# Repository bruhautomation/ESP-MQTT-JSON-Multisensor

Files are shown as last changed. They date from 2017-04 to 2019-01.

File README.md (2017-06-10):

# ESP MQTT JSON Multisensor

This project shows a super easy way to get started with your own DIY Multisensor to use with [Home Assistant](https://home-assistant.io/), a sick, open-source Home Automation platform that can do just about anything. 

Bonus, this project requires **no soldering** and **no breadboards** - just header wires and the development board! 

Video Tutorial - https://youtu.be/jpjfVc-9IrQ

The code covered in this repository utilizies Home Assistant's [MQTT JSON Light Component](https://home-assistant.io/components/light.mqtt_json/), [MQTT Sensor Component](https://home-assistant.io/components/sensor.mqtt/), and a [NodeMCU ESP8266](http://geni.us/cpmi) development board. 

### Supported Features Include
- **DHT22** temperature sensor
- **DHT22** humidity sensor
- **AM312** PIR motion sensor 
- **photoresistor** or **TEMT600** light sensor
- **RGB led** with support for color, flash, fade, and transition
- **Over-the-Air (OTA)** upload from the ArduinoIDE

#### OTA Uploading
This code also supports remote uploading to the ESP8266 using Arduino's OTA library. To utilize this, you'll need to first upload the sketch using the traditional USB method. However, if you need to update your code after that, your WIFI-connected ESP chip should show up as an option under Tools -> Port -> Porch at your.ip.address.xxx. More information on OTA uploading can be found [here](http://esp8266.github.io/Arduino/versions/2.0.0/doc/ota_updates/ota_updates.html). Note: You cannot access the serial monitor over WIFI at this point.  

### Parts List

**Amazon Prime (fast shipping)**
- [NodeMCU 1.0](http://geni.us/cpmi)
- [DHT22 Module](http://geni.us/vAJWMXo)
- [LDR Photoresistor Module](http://geni.us/O0AO0)
    OR
- [TEMT6000](http://geni.us/aRYe)
- [Power Supply](http://geni.us/ZZ1r)
- [Common Cathode RGB Led](http://geni.us/nFcB)
- [Header Wires](http://geni.us/pvFNG)
- [AM312 Mini PIR Sensor](http://geni.us/dbGQ)

**Aliexpress (long shipping = cheap prices)**
- [NodeMCU 1.0](http://geni.us/EfYA)
- [DHT22 Module](http://geni.us/35Np8H)
- [LDR Photoresistor Module](http://geni.us/O5iv)
    OR
- [TEMT6000](http://geni.us/xAuLoy)
- [Power Supply](http://geni.us/NSYjvb)
- [Common Cathode RGB Led](http://geni.us/OfHbhZb)
- [Header Wires](http://geni.us/Iv6p9)
- [AM312 Mini PIR Sensor](http://geni.us/WBKyxhx)

### Wiring Diagram
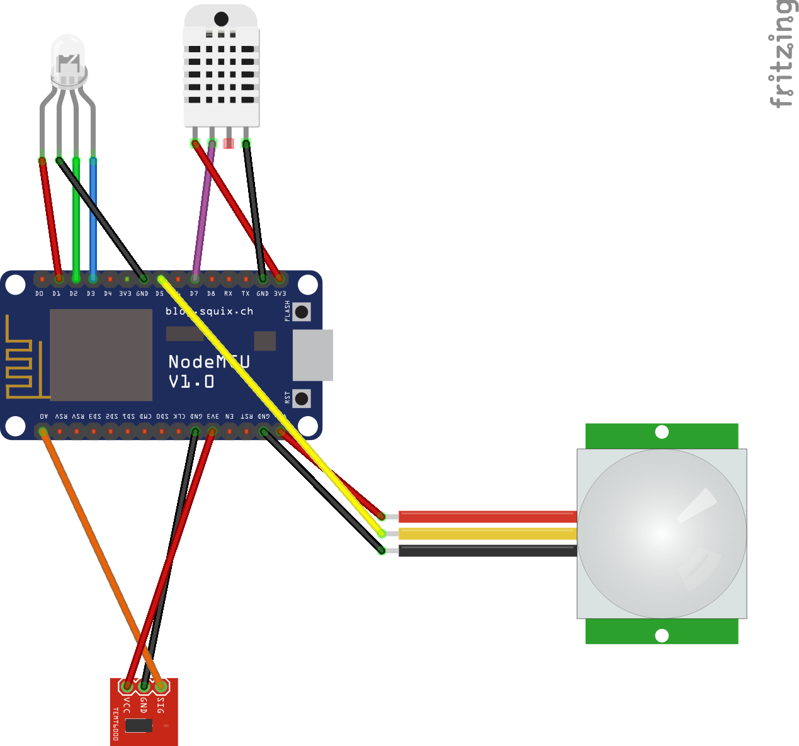
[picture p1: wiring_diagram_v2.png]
Wiring Diagram


### 3D Printed Enclosure
In an effort to make the sensor less ugly, I designed an enclosure in 123D Design and uploaded the [STL file](https://github.com/bruhautomation/ESP-MQTT-JSON-Multisensor/blob/master/BRUH%20Multisensor%20V1.stl) in case you want to print your own. It's also availible on [Thingiverse](http://www.thingiverse.com/thing:2239142). I printed mine on a [Prusa I3 clone](https://www.youtube.com/watch?v=PLRdMtZVQfQ) with a layer height of 0.2 mm, 40% infill, and no supports in [ESUN PLA](http://geni.us/GS3U) and it turned out great. 

Alternatively, you can also make your own enclosure by hand using something like [Instamorph](http://geni.us/BtidLG3). It's themoplastic that melts in hot water and then solidifies to hard plastic at room temperature. You can even get [pigment packs](http://geni.us/dNTi) and take it next level. I, personally, suck at using it, but it's cheap and functional. 

Of course, you can use a project box, tupperware, a card board box, or skip the enclosure all together. 

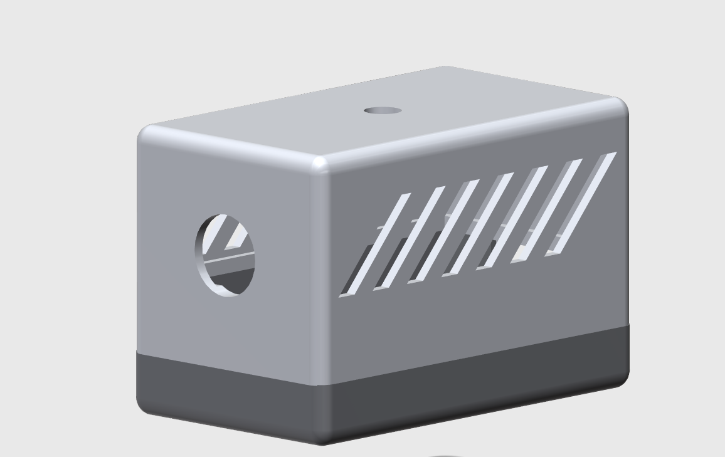
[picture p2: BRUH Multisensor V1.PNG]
Enclosure


### UPDATED 10 JUN 2017
I added a second version of my enclosure that moves the DHT22 sensor outside the case, removes the standoff for the LDR sensor, and adds a pocket for the LED. This should reduce most of the high temperatures being reported by the board and the removal of the standoff allows you to use either the TEMT600 sensor or photoresistor module. A dab of hot glue can help hold everything in place until you can snap the case together.

A few people have reported that the floating PIR sensor issue is back. If it happens, wrap the PIR module in electrical tape, then aluminum foil, and then electrical tape again. Using the tape will make sure you don't short anything out with the foil on either the module or other components in the system.

### Home Assistant Service Examples
Besides using the card in Home Assistant's user interface, you can also use the Services tool to control the light using the light.turn_on and light.turn_off services. This will let you play with the parameters you can call later in automations or scripts. 

Fade the Light On Over 5 Seconds - light.turn_on
```
{"entity_id":"light.sn1_led",
"brightness":150,
"color_name":"blue",
"transition":"5"
}
```

Flash The Light - light.turn_on
```
{"entity_id":"light.sn1_led",
"color_name":"green",
"brightness":255,
"flash":"short"
}
```

Fade the Light Off Over 5 Seconds - light.turn_off
```
{"entity_id":"light.sn1_led",
"transition":"5"
}
```

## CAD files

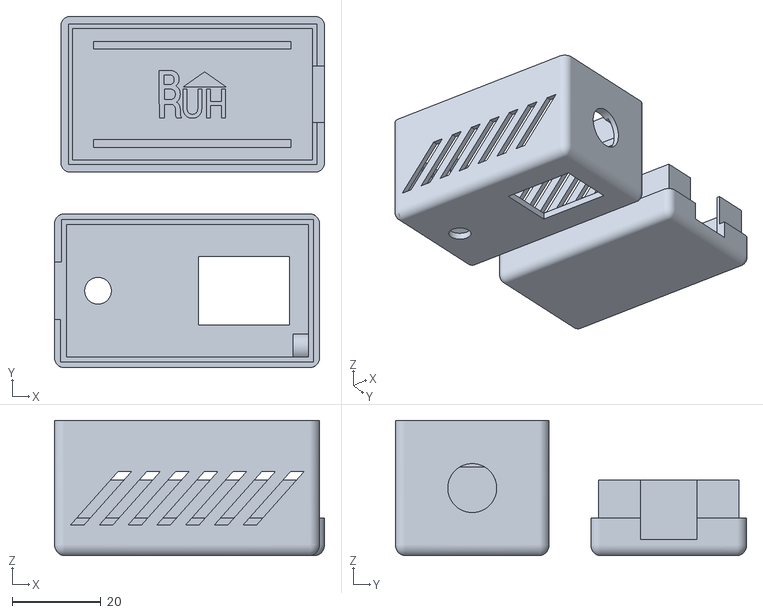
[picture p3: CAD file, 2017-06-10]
BRUH Multisensor V2.stl
60.7 x 78.9 x 30.4

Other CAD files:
BRUH Multisensor V1.stl

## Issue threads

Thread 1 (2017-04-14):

Feature request - support for Dallas ds18b20 temperature sensor

marksev1, 2017-04-14:
Hi,

this Dallas ds18b20 temperature sensor is a very commonly used temperature sensor besides the DHT22, could you maybe please add support also for it?

michaelmcarthur, 2017-04-27:
Hi Mark

I have added the ds18b20 temperature sensor to the multi sensor. It works by creating a extra json  "temperaturedallas" that works alongside the DHT11/22.  Just use the following in your Home Assistant sensor.yaml

`- platform: mqtt
  state_topic: "bruh/sensornode1"
  name: "SN1 Temperature"
  unit_of_measurement: "°C"
  value_template: '{{ value_json.temperaturedallas | round(1) }}'  `

To achieve this use the code bellow. It is the multi sensor code with the dallas sensor added in. You can search for all the changes by finding the word "add". Hope this helps.

`/*
  .______   .______    __    __   __    __          ___      __    __  .___________.  ______   .___  ___.      ___   .___________. __    ______   .__   __.
  |   _  \  |   _  \  |  |  |  | |  |  |  |        /   \    |  |  |  | |           | /  __  \  |   \/   |     /   \  |           ||  |  /  __  \  |  \ |  |
  |  |_)  | |  |_)  | |  |  |  | |  |__|  |       /  ^  \   |  |  |  | `---|  |----`|  |  |  | |  \  /  |    /  ^  \ `---|  |----`|  | |  |  |  | |   \|  |
  |   _  <  |      /  |  |  |  | |   __   |      /  /_\  \  |  |  |  |     |  |     |  |  |  | |  |\/|  |   /  /_\  \    |  |     |  | |  |  |  | |  . `  |
  |  |_)  | |  |\  \-.|  `--'  | |  |  |  |     /  _____  \ |  `--'  |     |  |     |  `--'  | |  |  |  |  /  _____  \   |  |     |  | |  `--'  | |  |\   |
  |______/  | _| `.__| \______/  |__|  |__|    /__/     \__\ \______/      |__|      \______/  |__|  |__| /__/     \__\  |__|     |__|  \______/  |__| \__|

  Thanks much to @corbanmailloux for providing a great framework for implementing flash/fade with HomeAssistant https://github.com/corbanmailloux/esp-mqtt-rgb-led

  To use this code you will need the following dependancies:

  - Support for the ESP8266 boards.
        - You can add it to the board manager by going to File -> Preference and pasting http://arduino.esp8266.com/stable/package_esp8266com_index.json into the Additional Board Managers URL field.
        - Next, download the ESP8266 dependancies by going to Tools -> Board -> Board Manager and searching for ESP8266 and installing it.

  - You will also need to download the follow libraries by going to Sketch -> Include Libraries -> Manage Libraries
      - DHT sensor library
      - Adfruit unified sensor
      - PubSubClient
      - ArduinoJSON

*/

#include <ESP8266WiFi.h>
#include <DHT.h>
#include <PubSubClient.h>
#include <ESP8266mDNS.h>
#include <WiFiUdp.h>
#include <ArduinoOTA.h>
#include <ArduinoJson.h>

// Add this here
#include <OneWire.h>
#include <DallasTemperature.h>
//

/************ WIFI and MQTT INFORMATION (CHANGE THESE FOR YOUR SETUP) ******************/
#define wifi_ssid "YourSSID" //type your WIFI information inside the quotes
#define wifi_password "YourWIFIpassword"
#define mqtt_server "your.mqtt.server.ip"
#define mqtt_user "yourMQTTusername"
#define mqtt_password "yourMQTTpassword"
#define mqtt_port 1883

/************* MQTT TOPICS (change these topics as you wish)  **************************/
#define light_state_topic "bruh/sensornode1"
#define light_set_topic "bruh/sensornode1/set"

const char* on_cmd = "ON";
const char* off_cmd = "OFF";

/**************************** FOR OTA **************************************************/
#define SENSORNAME "sensornode1"
#define OTApassword "bruh"
int OTAport = 8266;

/**************************** PIN DEFINITIONS ********************************************/
const int redPin = D1;
const int greenPin = D2;
const int bluePin = D3;
#define PIRPIN    D5
#define DHTPIN    D7
#define DHTTYPE   DHT22
#define LDRPIN    A0

// add this here This is pin D4
#define ONE_WIRE_BUS 2
//

/**************************** SENSOR DEFINITIONS *******************************************/
float ldrValue;
int LDR;
float calcLDR;
float diffLDR = 25;

float diffTEMP = 0.2;
float tempValue;

// add this here
float diffTEMPdallas = 0.2;
float tempdallasValue;
//

float diffHUM = 1;
float humValue;

int pirValue;
int pirStatus;
String motionStatus;

char message_buff[100];

int calibrationTime = 0;

const int BUFFER_SIZE = 300;

#define MQTT_MAX_PACKET_SIZE 512

/******************************** GLOBALS for fade/flash *******************************/
byte red = 255;
byte green = 255;
byte blue = 255;
byte brightness = 255;

byte realRed = 0;
byte realGreen = 0;
byte realBlue = 0;

bool stateOn = false;

bool startFade = false;
unsigned long lastLoop = 0;
int transitionTime = 0;
bool inFade = false;
int loopCount = 0;
int stepR, stepG, stepB;
int redVal, grnVal, bluVal;

bool flash = false;
bool startFlash = false;
int flashLength = 0;
unsigned long flashStartTime = 0;
byte flashRed = red;
byte flashGreen = green;
byte flashBlue = blue;
byte flashBrightness = brightness;

WiFiClient espClient;
PubSubClient client(espClient);
DHT dht(DHTPIN, DHTTYPE);

// add this here This gets onewire to communicate with the dallas temp sensor
OneWire oneWire(ONE_WIRE_BUS);
DallasTemperature sensors(&oneWire);
//

/********************************** START SETUP*****************************************/
void setup() {

  Serial.begin(115200);

// add this here
  sensors.begin();
//

  pinMode(PIRPIN, INPUT);
  pinMode(DHTPIN, INPUT);
  pinMode(LDRPIN, INPUT);

  Serial.begin(115200);
  delay(10);

  ArduinoOTA.setPort(OTAport);

  ArduinoOTA.setHostname(SENSORNAME);

  ArduinoOTA.setPassword((const char *)OTApassword);

  Serial.print("calibrating sensor ");
  for (int i = 0; i < calibrationTime; i++) {
    Serial.print(".");
    delay(1000);
  }

  Serial.println("Starting Node named " + String(SENSORNAME));

  setup_wifi();

  client.setServer(mqtt_server, mqtt_port);
  client.setCallback(callback);

  ArduinoOTA.onStart([]() {
    Serial.println("Starting");
  });
  ArduinoOTA.onEnd([]() {
    Serial.println("\nEnd");
  });
  ArduinoOTA.onProgress([](unsigned int progress, unsigned int total) {
    Serial.printf("Progress: %u%%\r", (progress / (total / 100)));
  });
  ArduinoOTA.onError([](ota_error_t error) {
    Serial.printf("Error[%u]: ", error);
    if (error == OTA_AUTH_ERROR) Serial.println("Auth Failed");
    else if (error == OTA_BEGIN_ERROR) Serial.println("Begin Failed");
    else if (error == OTA_CONNECT_ERROR) Serial.println("Connect Failed");
    else if (error == OTA_RECEIVE_ERROR) Serial.println("Receive Failed");
    else if (error == OTA_END_ERROR) Serial.println("End Failed");
  });
  ArduinoOTA.begin();
  Serial.println("Ready");
  Serial.print("IPess: ");
  Serial.println(WiFi.localIP());

}

/********************************** START SETUP WIFI*****************************************/
void setup_wifi() {

  delay(10);
  Serial.println();
  Serial.print("Connecting to ");
  Serial.println(wifi_ssid);

  WiFi.mode(WIFI_STA);
  WiFi.begin(wifi_ssid, wifi_password);

  while (WiFi.status() != WL_CONNECTED) {
    delay(500);
    Serial.print(".");
  }

  Serial.println("");
  Serial.println("WiFi connected");
  Serial.println("IP address: ");
  Serial.println(WiFi.localIP());
}

/********************************** START CALLBACK*****************************************/
void callback(char* topic, byte* payload, unsigned int length) {
  Serial.print("Message arrived [");
  Serial.print(topic);
  Serial.print("] ");

  char message[length + 1];
  for (int i = 0; i < length; i++) {
    message[i] = (char)payload[i];
  }
  message[length] = '\0';
  Serial.println(message);

  if (!processJson(message)) {
    return;
  }

  if (stateOn) {
    // Update lights
    realRed = map(red, 0, 255, 0, brightness);
    realGreen = map(green, 0, 255, 0, brightness);
    realBlue = map(blue, 0, 255, 0, brightness);
  }
  else {
    realRed = 0;
    realGreen = 0;
    realBlue = 0;
  }

  startFade = true;
  inFade = false; // Kill the current fade

  sendState();
}

/********************************** START PROCESS JSON*****************************************/
bool processJson(char* message) {
  StaticJsonBuffer<BUFFER_SIZE> jsonBuffer;

  JsonObject& root = jsonBuffer.parseObject(message);

  if (!root.success()) {
    Serial.println("parseObject() failed");
    return false;
  }

  if (root.containsKey("state")) {
    if (strcmp(root["state"], on_cmd) == 0) {
      stateOn = true;
    }
    else if (strcmp(root["state"], off_cmd) == 0) {
      stateOn = false;
    }
  }

  // If "flash" is included, treat RGB and brightness differently
  if (root.containsKey("flash")) {
    flashLength = (int)root["flash"] * 1000;
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
corbanmailloux, 2017-04-27:
@michaelmcarthur When pasting code in GitHub, wrap the code in three backticks (```).

Like:

\```
code
\```

michaelmcarthur, 2017-04-27:
Thanks for the advice @corbanmailloux  its my first time using github. Updated post

marksev1, 2017-05-09:
Are you gonna make a PR to the main code? :)

michaelmcarthur, 2017-05-09:
This code answers the question of adding ds18b20 sensors, but it isn't polished enough. I'm working on a way to create add on's to the code. This will allow any sensor to be added without changing the core code every time a sensor or switch is added. An example of this is @1technophile OpenMQTTGateway. It makes it very easy to add your own code as add on's.

marksev1, 2017-05-10:
Good plan. I would envision only maybe those new "radar sensors" which are like better than PIRs. To be another viable addition.

michaelmcarthur, 2017-05-11:
Those "radar sensors"  look really great. I would love to see a working DIY Arduino version of them. I have 433mhz transmitter and IR added to Bens code in the same way as I did the ds18b20. I find them really useful in my setup.

marksev1, 2017-05-11:
Yeah I'm also waiting for that...So if I find you some nice code, you will integrate those radar sensors too? :D ...Good I see you are mixing in a bit of OpenGateway also in right :), cool cool.

bruhautomation, 2017-05-11:
That's some great code. Thanks much for sharing @michaelmcarthur.

@marksev1, which radar sensor are you looking at? I tried several when working on this code, but I was having issues with RF interference. I'm still working to figure out the right series of decoupling capacitors to isolate the noise. Otherwise, I'll have to switch to an RF protocol and use a MQTT->RF bridge via something like MQTTOpenGateway.

Cheers,
Ben

marksev1, 2017-05-12:
@bruhautomation  this one: RCWL-0516, its very cheap, and works omnidirectionally (it even works through some not so thick walls), as opposed to PIR sensors.
This guy got it working with a esp8266: http://tech.scargill.net/microwave-for-the-weekend/

michaelmcarthur, 2017-05-12:
@marksev1 The RCWL-0516 motion sensor looks amazing, thank you for sharing. I have ordered one today should be with me next week. You should be able to hook it right up to the multi sensor. The RCWL-0516 sends a high signal when motion is detected so you should be able to remove the pir sensor from the multi sensor and add this one.

bruhautomation, 2017-05-12:
@marksev1  @michaelmcarthur Ah, gotcha! yeah, it's a great sensor. It works wonderfully on an Arduino. A couple of downsides so far in my early testing though.

1) On the NodeMCU it  is very susceptible to false positives. Long header wires reduce this. Shielding and decoupling capacitors could fix this, but I haven't found the magic sauce yet.

2) It's detection area is essentially a 360 degree sphere. When I used this on the second floor of my house, it detected motion when I walked around downstairs. That may not be an issue for some, but for room level automation this posed a challenge.

I'm curious to see how your attempts go! Let me know if you get it working. Cheers!

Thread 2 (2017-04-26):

Feature request - Support for a NeoPixel Ring - 12 x 5050 RGBW LEDs

hinrg, 2017-04-26:
Hi

Love your multi sensor :) do you think we can get support for a neo pixel ring rather then the LED. [https://littlebirdelectronics.com.au/collections/neopixel-rings/products/neopixel-ring-12-x-5050-rgbw-leds-w-integrated-drivers-cool-white-6000k](url) I'm working on a 3D printed case which i'll share once i'm done would be cool to have a led ring on the top like the google home ;)

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

Cheers,
J

bruhautomation, 2017-04-26:
Sweet enclosure! Looks great.

I would love to support the FastLED library (which supports neopixel rings) on this sketch. My long term goal is to merge my multisensor and led sketches into a single sketch. People can use whatever features they want from either.

This is on my list once I wrap up my blinds project. Looking forward to knocking that out soon.

Cheers,
Ben

hinrg, 2017-04-27:
Nice exactly what i was thinking!!!

msenebald, 2017-04-30:
i will be testing too 👍

Wilco89, 2017-06-07:
What is the state of your case? it looks very nice

cooljimy84, 2018-03-21:
Got myself a Neo Pixel ring, and a touch switch for local control.
If i get anywhere, i'll link here

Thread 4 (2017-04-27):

missing define mqtt_port

hinrg, 2017-04-27:
Hey Ben,

Latest version is missing #define mqtt_port 1883 ;)

Might also be worth adding that a fresh install of the SDK you need to install DHT sensor library and Adfruit unified sensor.

Cheers,
J

bruhautomation, 2017-04-27:
Ah, great catch! Thanks for pointing that out. Yeah, can't believe I missed the DHT library in my video. Guess I've had that installed for so long I'd forgotten about it. I'll add a note to the code. Cheers!

Closed 2017-04-27.

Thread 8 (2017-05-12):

MQTT not functional after Wifi disconnect

knutella, 2017-05-12:
About once a day my sensor would just stop being able to send or receive data over MQTT.  I could still ping the MCU.  The serial monitor showed nothing.

I was able to replicate the issue either by simply rebooting my router or using the Wifi MAC filter to temporarily block the MCU.  Afterwards the MCU would reconnect to wifi (as evidenced by the ping) but no longer function for MQTT send/receive.

TheFitzZZ, 2017-05-16:
I may experience the same issue. I have six sensors around the house and yesterday I noticed that two weren't sending updates anymore for no reason. Maybe we need some kind of automatic restart or so?

knutella, 2017-05-16:
I wrote a fix for this issue and submitted it, its been working reliably for about a week now.

[sketch_may04a.txt](https://github.com/bruhautomation/ESP-MQTT-JSON-Multisensor/files/1004853/sketch_may04a.txt)

bruhautomation, 2017-05-23:
Sorry about the issue! Knutella has a solid fix for this which I will merge ASAP. Thanks much for reporting it and for the fix @knutella!

TheFitzZZ, 2017-05-24:
Can confirm that this solves this issue perfectly, have been testing it since @knutella posted the fix.

bruhautomation, 2017-05-29:
I just merged this code into the repo so the fix should now be live. Thanks for the patch @knutella! Cheers!

Closed 2017-05-29.

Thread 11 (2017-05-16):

OSX not detecting the board

sjorsjes, 2017-05-16:
When you have the same problem as I had and the board is not detected on your Mac.
Installing these drivers fixed it for me: http://www.silabs.com/Support%20Documents/Software/Mac_OSX_VCP_Driver.zip

Found the solution in: http://rossbates.com/2016/01/30/getting-started-esp8266-osx/

bruhautomation, 2017-05-23:
Nice! Sorry about the issue, but I'm glad you got it working. Cheers!

Closed 2017-05-23.

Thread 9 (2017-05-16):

PIR Oddities!

jonathanweinberg, 2017-05-16:
Great tutorial / project! Having a slight issue with the PIR portion.

I initially wired everything up with a LDR (waiting on a TEMP6000), and an HC-SR501, and couldn't for the life of me get it to work, it was either all motion, or no motion. It was a cheapie and I figured it was the issue you described.

After long wait, my fancy AM312's got here! **Same thing.**

So I pulled out my analog meter, and saw very very little between Red (VIN) and Black (G) for the PIR sensor. So I move Red (labeled VIN) from it's place by the Black Ground, and up to the 3V by D4. Seems to be fine!

After 2-3 seconds it does show as standby if there's no active motion, but that's functionality to expect from the AM312 as I understand it.

Thoughts? Did I do something silly?

bruhautomation, 2017-05-23:
Sorry about the issue and my delay getting back to you. That's interesting about the issues with the AM312.

So, power the PIR from the 3V V pin near D4 made the sensor work for you? In normal operation, the PIR signal pin should remain low until it detects motion. It'll pull high for 2-3 seconds and then go low again automatically. Is this the behavior you're seeing?

bruhautomation, 2017-05-29:
Closing this due to inactivity. Feel free to reopen if you need to.

jonathanweinberg, 2017-07-05:
Reopening! :) Other similar issues #25 and #19

So, after looking at this more closely, I'm not sure why using VIN + GND + D5 would work. Keep in mind, I'm still trying to learn basic electronics.

The VIN pin, is literally as far as I know, [current into the NodeMCU voltage regulator](http://henrysbench.capnfatz.com/henrys-bench/arduino-projects-tips-and-more/powering-the-esp-12e-nodemcu-development-board/). It's how you would power the unit if not using a USB power adapter.

So we have `GND`, `Voltage into the NodeMCU`, and a `Digital Pin`. `GND` and `VIN` are both "sinks" of current. [In the Arduino sketch, the PIR pin `D5` is an input](https://github.com/bruhautomation/ESP-MQTT-JSON-Multisensor/blob/75fc667fd1309191c01965b2b5c3fb4d9fcb9c8d/bruh_mqtt_multisensor_github/bruh_mqtt_multisensor_github.i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)

Does my logic make sense or am I full of crazy talk here?

seanfilyaw, 2017-07-09:
I have wired according to the Diagram, in my instance I have a constant motion detected being displayed, on the Uxcell Mini Pyroelectric PIR Sensor I have the r2 red(vin) c3 yellow(signal) and r1 black(ground) I guess my question is do I have this wired correctly, It seems like it is constantly pulling high

jonathanweinberg, 2017-07-10:
@seanfilyaw - Question for you. Do you have a TEMT6000 in use? Or are you using an LDR?

seanfilyaw, 2017-07-10:
LDR

On Jul 9, 2017 10:39 PM, "Jonathan Weinberg" <notifications@github.com>
wrote:

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

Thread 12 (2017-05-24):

'setup_wifi' was not declared in this scope

DJSGXII, 2017-05-24:
I get the following error saying:
exit status 1
'setup_wifi' was not declared in this scope

Arduino: 1.6.7 (Windows 7), Board:"NodeMCU 1.0 (ESP-12E Module), 80 MHz, 115200, 4M (3M SPIFFS)"

C:\Users\User\Desktop\ESP-MQTT-JSON-Multisensor-master\ESP-MQTT-JSON-Multisensor-master\bruh_mqtt_multisensor_github\bruh_mqtt_multisensor_github.ino: In function 'void setup()':

bruh_mqtt_multisensor_github:164: error: 'setup_wifi' was not declared in this scope

   setup_wifi();

              ^

bruh_mqtt_multisensor_github:167: error: 'callback' was not declared in this scope

   client.setCallback(callback);

                      ^

C:\Users\User\Desktop\ESP-MQTT-JSON-Multisensor-master\ESP-MQTT-JSON-Multisensor-master\bruh_mqtt_multisensor_github\bruh_mqtt_multisensor_github.ino: In function 'void callback(char*, byte*, unsigned int)':

bruh_mqtt_multisensor_github:234: error: 'processJson' was not declared in this scope

   if (!processJson(message)) {

                           ^

bruh_mqtt_multisensor_github:253: error: 'sendState' was not declared in this scope

   sendState();

             ^

C:\Users\User\Desktop\ESP-MQTT-JSON-Multisensor-master\ESP-MQTT-JSON-Multisensor-master\bruh_mqtt_multisensor_github\bruh_mqtt_multisensor_github.ino: In function 'void loop()':

bruh_mqtt_multisensor_github:497: error: 'calculateStep' was not declared in this scope

       stepR = calculateStep(redVal, realRed);

                                            ^

bruh_mqtt_multisensor_github:512: error: 'calculateVal' was not declared in this scope

         redVal = calculateVal(stepR, redVal, loopCount);

                                                       ^

exit status 1
'setup_wifi' was not declared in this scope

DJSGXII, 2017-05-25:
Figured out I was running an outdated version of the Arduino IDE.
Updating to version 1.8.2 fixed the problem :)

Closed 2017-05-25.

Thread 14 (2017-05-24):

'D1' was not declared in this scope

DoomzKid, 2017-05-24:
I get this error when, Any Idea how to fix this ?

-------------------------------------------------------------
Multisensor:37: error: 'D1' was not declared in this scope

 const int redPin = D1;

                    ^

Multisensor:38: error: 'D2' was not declared in this scope

 const int greenPin = D2;

                      ^

Multisensor:39: error: 'D3' was not declared in this scope

 const int bluePin = D3;

                     ^

Multisensor:41: error: 'D7' was not declared in this scope

 #define DHTPIN    D7

                   ^

C:\Users\*****\Documents\Arduino\Multisensor\Multisensor.ino:105:9: note: in expansion of macro 'DHTPIN'

 DHT dht(DHTPIN, DHTTYPE);

         ^

C:\Users\****\Documents\Arduino\Multisensor\Multisensor.ino: In function 'void setup()':

Multisensor:40: error: 'D5' was not declared in this scope

 #define PIRPIN    D5

                   ^

C:\Users\*****\Documents\Arduino\Multisensor\Multisensor.ino:114:11: note: in expansion of macro 'PIRPIN'

   pinMode(PIRPIN, INPUT);

           ^

Multisensor:41: error: 'D7' was not declared in this scope

 #define DHTPIN    D7

                   ^

C:\Users\******\Documents\Arduino\Multisensor\Multisensor.ino:115:11: note: in expansion of macro 'DHTPIN'

   pinMode(DHTPIN, INPUT);

           ^

C:\Users\*****\Documents\Arduino\Multisensor\Multisensor.ino: In function 'void loop()':

Multisensor:40: error: 'D5' was not declared in this scope

 #define PIRPIN    D5

                   ^

C:\Users\*****\Documents\Arduino\Multisensor\Multisensor.ino:397:28: note: in expansion of macro 'PIRPIN'

     pirValue = digitalRead(PIRPIN); //read state of the

                            ^

exit status 1
'D1' was not declared in this scope

TheFitzZZ, 2017-05-24:
Please make sure you selected the right board.

DoomzKid, 2017-05-24:
Thanks !,

I was using the video on youtube,
Testing the file, But a bit further in the video.
Doas he the settings of the board. after that the code "D1" Error wiln't show,

Now i am only stuck at Serial Montitor with the message>

failed, rc=-2 try again in 5 seconds
Attempting MQTT connection...failed, rc=-2 try again in 5 seconds
Attempting MQTT connection...failed, rc=-2 try again in 5 seconds... ... ..

bruhautomation, 2017-05-29:
It's likely an issue with the MQTT server or credentials you are using. Verify your MQTT adress and the username/password info and try again. Cheers!

bbrendon, 2017-06-08:
I picked this board and I think my problem is fixed.

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

timmo001, 2017-10-16:
If that fixed your issue, make sure you hit close issue on this thread

Philje123, 2017-12-04:
I too had this "issue".

I was using an ESP-01 board and put D0 and D2. But they're not defined as data pins on the ESP-01. So if this is the case you have to just put 0 and 2 for these boards.

mmilton62, 2018-07-29:
Tks. I was using ESP8266 and had the same problem. Changed to ESP-12 1.0, as sudgested by bbrandon, and it all workrd.

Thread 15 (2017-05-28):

Getting very inaccurate temperature readings

TheFitzZZ, 2017-05-28:
Hey guys,

I have six of the sensors around the house, some also where already other sensors exist, so  I can compare the results. Something I don't really need another sensor for is the fact, that the remperature is off by some extend. It's always way too high by 5-10°C - same error with °F btw.

Any ideas what could cause this? It makes them practially useless.

Thanks

tariquesani, 2017-05-28:
Do you by any chance have DHT11 rather than DHT22

TheFitzZZ, 2017-05-28:
No, but I think I see the issue now: the case. I think it heats itself up and the ventilation by the few left-outs isn't enough by any chance to get proper readings.

How I know this? I aimed a little USB ventilator at the box to get some airflow. And voila, the temperature seems much more likely to be correct: went from 31°C to 24° - which seems reasonable.

I will verify further, design a new case and make a pull request for it once I've tested it ... will take some time though :-)

bruhautomation, 2017-05-29:
Yeah, in doing some testing with this tonight. It does appear that the case is causing the heating issues. Sorry about that! You could add an offset in the code, but that's not a great solution. I'm going to redesign the case and move the sensor further from the board. That should help.

@TheFitzZZ, if you come up with a new case design, too. I'd be happy to post the link or host the STL in the repo if you want!

Cheers!

gillrishi, 2017-05-30:
Hi
I am using dht11 sensor.
 it shows temprature 987 c and humidity 1098%.
Can you help me out to fix this issue?
Thanks

tariquesani, 2017-05-30:
@gillrishi get a dht22

gillrishi, 2017-05-30:
Ok..
Thanks for your help

bruhautomation, 2017-06-02:
Yeah DHT11 sensors aren't as great. If you use a DHT11, make sure you set line 73 to

```
#define DHTTYPE   DHT11
```

Cheers!

cbrherms, 2017-12-03:
Looks like the V2 case might be doing something similar though. i'm getting about 5C difference even on the new case.

martinjuhasz, 2018-01-09:
Same here, its related to the case. Having the sensor some cm outside of the box shows me the correct temp.

Any ideas what we can do about this?

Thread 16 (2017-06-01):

Compilation issue on Arduino 1.8.2 on Linux !

vincegre, 2017-06-01:
Following your great youtube tutorial for setup of the MQTT client with ESP8266 boards !
I have copy/pasted your code from GitHub in Arduino IDE 1.8.2 running on Ubuntu 16.04.2 (I have added all libraries as indicated in your video). I then edited the few lones for Wifi setup, network and MQTT server.
When I try to compile code I have an error:

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

Missed something ? I just checked your video but it looks like I have missed none steps :(

Thanks

Vincèn

bruhautomation, 2017-06-02:
Are you using a NodeMCU 1.0 board? You might try selecting that in the board manager (if you haven't yet) and see if that helps. Sorry about the issues!

vincegre, 2017-06-02:
@bruhautomation Unhappy not ! I use the ESP board as I follow your tutorial !

bruhautomation, 2017-06-02:
Looking at your error log there is appears you have the ESP8266 board selected?
```
Arduino : 1.8.2 (Linux), Carte : "Generic ESP8266 Module, 80 MHz, 40MHz, DIO, 115200, 512K (64K SPIFFS), ck, Disabled, None"
```

You should select NodeMCU 1.0.

vincegre, 2017-06-02:
@bruhautomation ah yep works fine and compile with success ;) sorry for mistake ! and thanks for help !

Closed 2017-06-02.

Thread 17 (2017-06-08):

Compliation issues

amitubale, 2017-06-08:
Hi anyone able to compile the code with the new versions o the packages ?.

 i tries for a whole day and gave up. i kept getting the IRemote..error. I removed the folder but no luck. since i waited @a month had to get the sensor working so i have espeasy on it now and got the 3 sensors working. (not sure how to get the color led configured on esp..so i need to get Ben's code compiled..

I iwll try it again and post the error.
let me know if you are bale to compile with the new pakages ? thanks

amitubale, 2017-06-09:
i was able to compile after adding the DHT.h lib and had to add #include <Adafruit_Sensor.h> above dht.h
and it connects to Wifi too. took me while to realize there i no webserver in the code(or did i miss another lib ?)

tariquesani, 2017-06-09:
No, there is no webserver but you can see output in the serial monitor. This works best with Home Assistant

amitubale, 2017-06-09:
awesome..lean code..thanks

ArjenWols, 2017-07-25:
Compilation error on Adafruit_Sensor.h
Solved with this:   https://github.com/adafruit/DHT-sensor-library/issues/62
Regards
Arjen

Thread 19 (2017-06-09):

No Change in PIR Motion Detected State

epleypa, 2017-06-09:
I'm running into an issue where there does not seem to be any change from "Motion Detected" back to "standby." Since I'm new to the ESP and PIR, any tips on troubleshooting? I've tried two different PIR modules with no changes, both report motion as soon as the board has booted. The code seems to be working as I get standby if I unplug Vin from the PIR. Could be bad hardware, but I'm unsure. Thanks!

tariquesani, 2017-06-09:
Which PIR are you using? Does it have setting for delay and repeater?

epleypa, 2017-06-09:
I am using the mini PIR AM312 from Ben's Aliexpress link: https://www.aliexpress.com/item/Mini-IR-Pyroelectric-Infrared-PIR-Motion-Human-Sensor-Automatic-Detector-Module-high-reliability-12mm-x-25mm/32749737125.html. I don't think it has a setting for delay or repeat from what I can tell.

epleypa, 2017-06-10:
Looks like it was a bad PIR and Vin on the ESP8266, just got it working on another set

Closed 2017-06-10.

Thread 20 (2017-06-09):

Bad data send when reboot

wanghuangjie, 2017-06-09:
{"state":"OFF","color":{"r":255,"g":255,"b":255},"brightness":255,"humidity":"0.00","motion":"motion detected","ldr":"0","temperature":"0.00"}
{"state":"OFF","color":{"r":255,"g":255,"b":255},"brightness":255,"humidity":"0.00","motion":"motion detected","ldr":"757","temperature":"0.00"}
{"state":"OFF","color":{"r":255,"g":255,"b":255},"brightness":255,"humidity":"0.00","motion":"motion detected","ldr":"757","temperature":"86.00"}

Multisensor will send "0" when reboot, please help if there is any solution .

jumpalottahigh, 2017-06-25:
Hi. I seem to have a similar issues - the multisensor does not report humidity for some reason. Everything else works fine and I know it's not a faulty sensor, since I tested it separately, and also tested with a second DHT22 sensor. Will look into this today and let you know if I figure something out.

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

jumpalottahigh, 2017-06-25:
Double check your code, I had a spelling mistake (although the program would still compile).
Had a `float newHumValue = dht.read();` which should have been float `newHumValue = dht.readHumidity();`. No idea how that happened, but everything works like a charm.

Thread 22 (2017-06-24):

LDR all over the place

melsom, 2017-06-24:
Hello,

Is there any way to correct this? The sensor i stationary but the values seems to be up/down alot even though the median seems to be correct, looking at the 24h logs.

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

cooljimy84, 2017-07-03:
I get this when someone walks in front of the sensor. I was thinking of using a diffuser on top of it to try and level it out a bit.
I also have a 30 minute window where the sun bounces off cars going past and they reflect into the flat causing it to read higher for a second or so....

jonathanweinberg, 2017-07-05:
Also, if you're using an LDR, `lux` is an arbitrary thing in that scale, you aren't getting true `lux` values.

ntalekt, 2017-07-09:
I got this too and realized it was my ceiling fan throwing shadows all over the place. I moved the sensor to a place that isn't affected and mounted in an enclosure and it's been rock solid.

Jizar07, 2017-11-19:
I got a different issue , my sensor works backwards, if its dark the numbers goes up to about 600 lux, if is bright is goes down to 33 lux. , I got the 4 pin sensor and got signal pin on AO (analog output) instead of DO (digital output). already tried switch AO and DO, but got the same result. any help would be greatly appreciated.

cooljimy84, 2017-11-21:
correct (well for me as well) so darkness for my sensor is 900 LUX and bright light is 20 odd.

rdbahm, 2017-12-08:
@Jizar07 At least with an LDR, this happens if  your ground and 3v are swapped.

mikewebb70, 2019-02-02:
> @mikewebb70 - you should share that template :)

You are right I should have, it's nothing special.  Here is my light sensor Home Assistant yaml entry

```
- platform: mqtt
  name: "flux office"
  state_topic: "tele/labmcu/SENSOR"
  unit_of_measurement: "%"
  #value_template: "{{ value_json['ANALOG'].A0 }}"
  value_template: "{{ (value_json['ANALOG'].A0|float/1024*100|float)|round(0) }}"
  availability_topic: "tele/labmcu/LWT"
  payload_available: "Online"
  payload_not_available: "Offline"
```

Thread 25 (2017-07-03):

My board not supplying 5V on VIN (floats around 2-2.2 volts)

cooljimy84, 2017-07-03:
Easy fix, use a 3V rail, but be worth noting on the wiring image.

bruhautomation, 2017-07-07:
What kind of power supply are you using? You should be getting the power straight from the supply on that pin. Or at least that's my understanding.

cooljimy84, 2017-07-08:
I think its my clone board, reading more into it they might be using that pin as a battery charging pin ?!?

I'd close this, as I just wanted to note it for someone.

Also thanks for the awesome Vids, I was ready to give up with HASS, due to lots of command line editing, but it's soooooo powerful !

Closed 2017-07-08.

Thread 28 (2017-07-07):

Temp in C not F?

markrennie71, 2017-07-07:
Hello

This is my 1st project like this and I love it thank you. Since I am English, how do I get it to display the temperature in C not F please?

Cheers
Mark

AaronLayton, 2017-07-25:
Hi @markrennie71

Easy - just remove the `true` from this line
https://github.com/bruhautomation/ESP-MQTT-JSON-Multisensor/blob/master/bruh_mqtt_multisensor_github/bruh_mqtt_multisensor_github.ino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

so it should read

```
float newTempValue = dht.readTemperature();
```

nagash, 2017-07-26:
I believe changing the recommended line of code causes the "Real Feel" value to be incorrect as the real feel algorithm uses the same temp value but is hard coded against F.

FWIW, using home assistant, I left the value as F and noted that the input was F in the sensor config. I've got my units set to metric in home assistant config, and it "just worked". I get my values in Home Assistant in celsius and when I write automations I also specify celsius values.

markrennie71, 2017-07-26:
thanks guys, yeah I already found that and found the real free is incorrect. They are only for my loft and garage, so real free isn't required for me :)

AaronLayton, 2017-07-26:
Yeah good points 🔼
Maybe that needs to be put into a setting so it can be easily changed

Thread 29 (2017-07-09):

LDR Time Series

ntalekt, 2017-07-09:
Anyone else having this weird time series issue? The lights were off (0 LUX) until 1:27:33PM when I turned them on for a little bit. Instead of the time series being 0 for the time period before I turned on the light there is a diagonal line. Almost like HA isn't logging the 0 data points.

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

AaronLayton, 2017-07-25:
I have not had this, although, my LUX seems to be backwards - so I get a higher value when it's dark

kernelheap, 2017-08-15:
my LUX is backwards too. If I throw the iphone flashlight on it, it indicates 80 lux. Otherwise it says 565 lux. Not sure whats wrong.

kwinck, 2017-08-29:
HA does not update if the new value is the same as the previous value. That causes the spike. Try to append
`force_update: true`
the the sensor definition.

https://community.home-assistant.io/t/force-update-settings-for-all-components-from-configuration-yaml/2198

rdbahm, 2017-10-24:
@kernelheap Reverse your VCC and GND lines.

Suggest this issue be closed for this repo as it's a Home Assistant quirk, not a problem with the sensor.

ntalekt, 2017-10-24:
@rdbahm Agreed. Thanks!

Closed 2017-10-24.

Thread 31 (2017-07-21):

Temp going up when cooling (have changed to Celsius)

pornstrup, 2017-07-21:
Thanks for a great multisensor-node.

I have a problem with the temp-sensor. When blowing cool air to the sensor it gives higher values (ex. going from 25 Celsius to 35 Celsius). I have tried to switch the 3v and G wires without effect. Im using the DHT22 temp-sensor you have a link to in readme. I have no clue whats wrong.

bachoo786, 2017-07-25:
I am having the same issues as you. Not getting the correct temperature readings shows warm temperature by 5 to 8 degrees than the current temperature. Any ideas on how to resolve this issue?

Closed 2017-07-21.

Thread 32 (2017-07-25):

Will code work with D1 Mini V2 NodeMcu board?

DNA99, 2017-07-25:

DNA99, 2017-07-25:
Hi,

I would like to do this project with the D1 Mini V2 NodeMcu board. Does anyone know if the same code will work on that board?

AaronLayton, 2017-07-25:
Hi @DNA99

The code should be compatible as its still based off the **ESP8266** chipset. As this board has less pin outs, you would need to put it on some breadboard so you can share the GND and 3v / 5v rails

Closed 2017-07-28.

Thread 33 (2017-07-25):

Incorrect Temperature Readings

bachoo786, 2017-07-25:
Hi thanks for the amazing sensor diy.

I have followed everything as per the instructions but my dht22 sensor gives me incorrect temperature readings by 5 to degrees more than the current room temperature.  I have changed the dht22 sensor hoping it was faulty but I get the same problem with a new dht22 sensor.

Has anyone come across this issue before?

Any help will be appreciated thanks.

DanielXYZ2000, 2017-10-15:
According to the datasheet the accuracy is <+-0.5°C. Large deviations could be based on the sensor position (housing, light exposure, convection,...) or maybe the sensor is defect?

mr-sneezy, 2018-04-26:
This could be from heat soaking from the NodeMCU board...
If the DHT22 is close to the WiFi RF chip or the 5V-3.3V regulator, especially mounted above it, the small amount of heat is enough to raise the temp of the sensor by as much as 5 degrees. Found out the hard way myself.
Also, it pays to only sample the DHT22 infrequently as possible, as it self heats while doing the conversions. They recommend no more than about once in 5 seconds IIRC. Can't see why the sensornode would need to be any more than every 15 seconds or more...

soppilif, 2019-03-18:
im experiencing similar issues.
Before using the enclosure, DHT22 was giving me 1 correct reading out of 5. That is:
one reading was -10 C , next reading was the correct one 21 C and next ones same as -10 C.
Similar with humidity...
Once i used the enclosure i was getting stable readings of 12 C temperature and 22% humidity which again were incorrect.
My enclosure was a Pringles box dropped to its minimun possible height.
I removed the DHT22 at the moment until i find a solution.
Any ideas?

mr-sneezy, 2019-03-19:
That's not the same issue, such a big deviation in both directions sounds like a power supply issue  (to the sensor or the NodeMCU) . Try a large (470uF or bigger) capacitor on the 5V supply rail and ground, then if that makes not difference maybe check for wire or pin connection problems.

soppilif, 2019-03-22:
> That's not the same issue, such a big deviation in both directions sounds like a power supply issue (to the sensor or the NodeMCU) . Try a large (470uF or bigger) capacitor on the 5V supply rail and ground, then if that makes no difference maybe check for wire or pin connection problems.

tried different pins and jumpers but same behaviour. The moment i unplug and replug the jumpers one or two readings are correct and then it gets faulty.
Should i get another DHT? I cant solder capacitors.
PIR and LDR work fine.

mr-sneezy, 2019-03-22:
Do you have an Arduino board at all (Nano, Mini etc will do), if so wire it to that and try any test code on Git via the serial terminal and see if it reads right to prove the DHT is OK.
BTW, it's my understanding that Bruh has abandoned this code and now doing same stuff via a new system.

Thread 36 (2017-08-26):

temperature and heatIndex values on first boot up

ericstewart22, 2017-08-26:
Hello,

Whenever I unplug my sensor or it loses power, the temperature and heatIndex values default to 0 and get sent to my MQTT broker which then makes its way into Home Assistant and results in a spike in the charts.

Here's an example of what it looks like:
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

I tried adjusting the calibrationTime variable but that didn't work. What would be the recommended way to fix this?  Is it as simple as using a counter to disregard the first few MQTT values? If it is then maybe I can try and fix it myself, but I thought there might be a better way.

knutella, 2017-08-26:
I added this to the SendState void function.  I basically doesn't send if its below 1.  I'm sure something more elegant like just sending a NULL would be better but this works for me

if (tempValue<1) {
        Serial.println("less than 1");
      }
  else {
  Serial.println(buffer);
  client.publish(light_state_topic, buffer, true);

kwinck, 2017-08-29:
My take on that issue is to have a timer, that ensures that it doesn't send any values the first 30 sec. or so, ie. until the calibration period is done.

ericstewart22, 2017-08-31:
Thanks for the input, I'm going to use the tempValue < 1 for now but I'll try my hand at using a timer when  I have more time.

lassivv, 2017-10-23:
Same problem and try add capacitor on power line and better 5volt supply power, nothing help not know why sensor restart/softstart every day random couple times.

After that i add this code in sendstate function and everything works perfectly after that. Think every tips/hints here work too:

byte countSentStates = 0;

  if(countSentStates <= 2)
  {
    countSentStates++;
    return;
  }

mr-sneezy, 2018-04-26:
lassivv, I get these dropouts also, on two sensornodes. It seems to be a random reset from something unknown. It's not power related as I've covered that through elimination and also adding large fiters caps (1800uF) to the 5V input of the NodeMCU's just in case.
My graphs of 24 data look very like yours with data dropouts to below zero on temp and humidity when these events occur.
When it does this the RGB LED also goes to blue and stays that way till I send a "White' colour to it and then 'Off' via HA Light component GUI.

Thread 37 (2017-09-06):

Problems compiling sketch

PilotC150, 2017-09-06:
Not sure what's happening here.  I followed all the directions and I'm just trying to get the main sketch to compile but I'm getting errors with the ESP8266WiFi library.

(I tried putting this in a code block but there's too many single quotes in there for it to get formatted correctly.)

I tried updating to latest Arduino IDE and updating all boards and libraries but still getting the error.

Any idea what could be causing these errors?

C:\Users\Chris\Documents\Arduino\libraries\ESP8266WiFi\src\ESP8266WiFi.cpp: In member function 'void ESP8266WiFiClass::beginSmartConfig()':

C:\Users\Chris\Documents\Arduino\libraries\ESP8266WiFi\src\ESP8266WiFi.cpp:393:76: error: cannot convert 'sc_type' to 'sc_callback_t {aka void (*)(sc_status, void*)}' for argument '1' to 'bool smartconfig_start(sc_callback_t, ...)'

     smartconfig_start(SC_TYPE_ESPTOUCH, &ESP8266WiFiClass::_smartConfigDone);

                                                                            ^

C:\Users\Chris\Documents\Arduino\libraries\ESP8266WiFi\src\ESP8266WiFi.cpp: In member function 'bool ESP8266WiFiClass::smartConfigDone()':

C:\Users\Chris\Documents\Arduino\libraries\ESP8266WiFi\src\ESP8266WiFi.cpp:409:35: error: 'smartconfig_get_status' was not declared in this scope

     return smartconfig_get_status() == SC_STATUS_LINK_OVER;

                                   ^

Multiple libraries were found for "ESP8266mDNS.h"
 Used: C:\Users\Chris\Documents\Arduino\libraries\ESP8266mDNS
 Not used: C:\Users\Chris\AppData\Local\Arduino15\packages\esp8266\hardware\esp8266\2.3.0\libraries\ESP8266mDNS
Multiple libraries were found for "ESP8266WiFi.h"
 Used: C:\Users\Chris\Documents\Arduino\libraries\ESP8266WiFi
 Not used: C:\Users\Chris\AppData\Local\Arduino15\packages\esp8266\hardware\esp8266\2.3.0\libraries\ESP8266WiFi
exit status 1
Error compiling for board NodeMCU 1.0 (ESP-12E Module).

DanielXYZ2000, 2017-10-03:
Hi,
I just compiled the current verision successfully.
I had a similar problem with multiple libraries and had parallel installation of the arduino IDE (normal installation and portable version) - After removing all an a fresh clean installation I got it work. Sorry that I can't give more details.

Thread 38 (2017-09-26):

Blue light on sensor startup

sjorsjes, 2017-09-26:
I've got 7 BRUH multisensors up and running and I love them and I have 0 problems with them so far!

The only thing that bothers me is that I can't get rid of the blue light. It lights up when I'm connecting it to power but also on, which feels, random times. I could not find anything about this in the code so I was hoping you could push me in the right direction.
I noticed some people in the youtube comments have the same issues.

Thanks and keep up the awesome work!

knutella, 2017-09-26:
I had the same issue, I added this to the code to make it go away

void setup() {

  Serial.begin(115200);

  pinMode(PIRPIN, INPUT);
  pinMode(DHTPIN, INPUT);
  pinMode(LDRPIN, INPUT);

  **//new code to turn LED on then off
  analogWrite(redPin, 1);
  analogWrite(greenPin, 1);
  analogWrite(bluePin, 1);
  analogWrite(redPin, 0);
  analogWrite(greenPin, 0);
  analogWrite(bluePin, 0);**

  delay(10);

mr-sneezy, 2018-04-26:
Yes among other issues my blue LED goes on randomly or perhaps also after a reset.
I'm just a newbie at Arduino C coding, can you tell me why you declare the RGB pins as inputs and then toggle them as output ?

BertrumUK, 2018-11-05:
You can also stop it by moving the Blue LED leg from D3 to D4 and changing the code to match.

I like the affect as it lets me know if there is an issue with Hassio or MQTT that I need to look into.

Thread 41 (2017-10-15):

Random 0values on HA logging

lassivv, 2017-10-15:
Build sensor and leave led hardware out. Sensors readings are perfect and seems very accurate.

But randomly couple times of days, every sensor take 0value (temp, humidity, brighness)

Here example picture:
https://i.imgur.com/dSYydNj.png

lassivv, 2017-10-22:
Anyone have same type problems or do i only have them :)

Now i have couple sensor. Other is this wiring method what this page shows. Other is totally planned circuit board.

Wiring method here still keep giving that 0values 3-6times per day.

My circuit board model gives only one that kind 0values on day. Circuit board model is longer distance to wlan router than original model. Bad wlan signal is not that problem then.

....

One solution maybe if you can take of that 0values when bruh multisensor arduino soft boot. I think sensor do boot and because that i get that 0values. (because if i watching serial monitor on sensor everytime when i boot that that gives couple times 0values before that gives right values.

Hope someone have same problems and can give some tips.

knutella, 2017-10-23:
This looks like the same issue as https://github.com/bruhautomation/ESP-MQTT-JSON-Multisensor/issues/36

lassivv, 2017-10-23:
Confirm that, just some reason not see that issue, when i do my issue number.

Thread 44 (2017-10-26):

I don't see any MQTT messages in a client.

ravensteijn, 2017-10-26:
Hi,
I Like this multisensor a lot! I have one problem. ik don't see the messages in an MQTT client. like MQTT spy. When i subscribe to topic # i don't get any messages. I have owntracks on my phone and that works great in HASSIO mosquitto.

Can anybody help what to look for?

This is the serial monitor in arduino IDE.

```
...
WiFi connected
IP address:
192.168.1.13
Ready
IPess: 192.168.1.13
Attempting MQTT connection...connected
Setting LEDs:
r: 0, g: 0, b: 0
{"state":"OFF","color":{"r":255,"g":255,"b":255},"brightness":255,"humidity":"0.00","motion":"","ldr":"0","temperature":"0.00","heatIndex":"nan"}
{"state":"OFF","color":{"r":255,"g":255,"b":255},"brightness":255,"humidity":"0.00","motion":"standby","ldr":"0","temperature":"0.00","heatIndex":"nan"}
{"state":"OFF","color":{"r":255,"g":255,"b":255},"brightness":255,"humidity":"0.00","motion":"standby","ldr":"60","temperature":"0.00","heatIndex":"nan"}
{"state":"OFF","color":{"r":255,"g":255,"b":255},"brightness":255,"humidity":"0.00","motion":"standby","ldr":"60","temperature":"21.60","heatIndex":"nan"}
{"state":"OFF","color":{"r":255,"g":255,"b":255},"brightness":255,"humidity":"67.70","motion":"standby","ldr":"60","temperature":"21.60","heatIndex":"16.64"}
```

ravensteijn, 2017-10-27:
Never mind. I now use this source.
https://github.com/ShawnCorey/ESP-MQTT-Multisensor-Authdiscovery

redparchel, 2017-11-28:
just wanted to follow up on this in case anyone else has this issue. as I had a similar issue and found my issue to be that I hadn't modified the PubSubClient.h from the PubSubClient library
modifying the MQTT_MAX_PACKET_SIZE to be '512' as mentioned in Ben's video: [https://youtu.be/jpjfVc-9IrQ?t=10m42s](https://youtu.be/jpjfVc-9IrQ?t=10m42s)

from:
`#define MQTT_MAX_PACKET_SIZE 128`
to:
`#define MQTT_MAX_PACKET_SIZE 512`

Closed 2017-10-27.

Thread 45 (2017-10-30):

PIR sensor false trigger and optimal time for delay after PIR detect motion

sumitrajancse, 2017-10-30:
Hi,
      Its is a very awesome DIY product. Although the PIR sensor trigger false alarm, and the detection distance is very small.
I would recommend using a RCWL 9196 / RCWL-0516 radar motion detector module as it had zero interference with nodeMCU module and greater detection distance.

Also it will be very helpful if you can share you experience on the delay time after a motion is detected (default in the code is 100ms, I guess 2 minutes will be a good time before checking and chanigng the state again.

Please suggest.

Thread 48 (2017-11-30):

LED flickering when motion is detected

markusressel, 2017-11-30:
Hi there,

great piece of code already. I have a small issue that I would like to fix (if possible).
First a little bit about my setup:

I use a single NodeMCU with all of the sensors and an RGB LED attached.
I use a dedicated MQTT server that is connected with the NodeMCU and Home Assistant.
In Home Assistant I have an automation set up that turns on the LED of the NodeMCU using the MQTT method and another automation that turns it off when there is no motion anymore.

At first I had an issue with "flickering states" in Home Assistant that would constantly trigger the "on" and "off" automation even when there was movement at all times.

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

I was able to fix this by introducing a small timeout before setting the ```pirValue``` to "standby" or ```pirState = 2``` like this:

```
int pirValue;
int pirStatus;
int lastTimeMotionDetected = 0;
String motionStatus = "standby";

[...]

pirValue = digitalRead(PIRPIN); //read state of the

if (pirValue == HIGH) {
  lastTimeMotionDetected = millis();

  if (pirStatus != 2) {
    motionStatus = "motion_detected";
    sendState();
    pirStatus = 2;
  }
}
// add a timeout of 5 second before switching to standby to prevent "state flickering" in home assistant when motion is detected
else if (pirValue == LOW && pirStatus != 1 && (millis() > (lastTimeMotionDetected + 5000))) {
  motionStatus = "standby";
  sendState();
  pirStatus = 1;
}
```

**However** even though the LED is turned on at all times and Home Assistant doesn't turn it on and off constantly the LED itself flickers in a seemingly random interval of 1-2 seconds while movement is detected. At first I thought this was due to the fact that Home Assistant was switching states but now that Home Assistant doesn't do this anymore I'm kinda out of ideas.

Does someone know why this happens and how to fix this?

Home Assistant is not turning it on and off:
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
(Yes I was actually standing there waving my arms for 2 minutes... xD)

rdbahm, 2017-12-08:
Does the issue still occur if you set it to 100% white? I'm wondering if the AnalogWrite is being interrupted by the main loop, which would cause visible flickering. If it's set to 100% white, it shouldn't flicker if this is the case.

I also assume you're not using the "transition" feature to fade between "off" and "on" states?

markusressel, 2017-12-08:
I'm not sure if I understand what you mean by that.
My Home Assistant automation looks like this (there is no color specified):
```
- alias: 'NodeMCU1: Motion detected'
  hide_entity: True
  trigger:
    - platform: state
      entity_id: binary_sensor.nodemcu_1_pir
      from: 'off'
      to: 'on'
  action:
    - service: homeassistant.turn_on
      entity_id: light.nodemcu_1_led

- alias: 'NodeMCU1: No motion anymore'
  hide_entity: True
  trigger:
    - platform: state
      entity_id: binary_sensor.nodemcu_1_pir
      from: 'on'
      to: 'off'
  action:
    - service: homeassistant.turn_off
      entity_id: light.nodemcu_1_led
```

This is the definition of the LED in Home Assistant:
```
# Multisensor 1
- platform: mqtt_json
  name: "NodeMCU_1 LED"
  state_topic: "/home/multisensor/NodeMCU_1"
  command_topic: "/home/multisensor/NodeMCU_1/set"
  brightness: true
  flash: true
  rgb: true
  optimistic: false
  qos: 0
```

Should I turn off the "flash" option to prevent this? Or what exactly is this option used for?

I don't use the "transition" feature currently. Maybe I should check this out and see if it helps.

rdbahm, 2017-12-08:
Try just disabling the "flash" option - what "flash" does is temporarily
override the current light color with the requested light color - would
almost definitely cause flickering.

I asked about "transition" because the codepath for handling transitions is
totally separate from normal processing and might be somewhat more
vulnerable to problems like this.

On Fri, Dec 8, 2017 at 2:22 AM Markus Ressel <notifications@github.com>
wrote:

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

markusressel, 2017-12-12:
Thanks for your help.

I turned off the "flash" option now. I'm not quite sure though if this really was the issue as I couldn't reproduce the flickering in the last days (hence the delay in response). I will close this issue though as it seems to be fixed.

Closed 2017-12-12.

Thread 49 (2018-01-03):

Sensor Data in Serial but not in HA

ill-tempered, 2018-01-03:
I can see the data scrolling in the serial connection but HA readings are all UNKNOWN.

topic subscribed in HA (MQTT) is correct

LED control works

**UPDATE: Nevermind - it was the MQTT MAX packet size parameter in PubSub Library**

consolacion, 2018-07-14:
is your MQTT broker setup correctly? is your  device connecting to it?
Check the traffic with e.g. MQTTspy

Closed 2018-07-14.

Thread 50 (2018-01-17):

Light "blinking"

lassivv, 2018-01-17:
Problem is i use only one led strip on one "rgb" channel. Because that is normal white strip. I use home assistant white color and only change brightness.

Problem is every time when i put led on that blink (i think full power some period maybe 10-30ms and after that be normal). After about 5-10s do same and continue that forewer. If put light off or pwm 0 then strip be totally shutdown.

Not can use that lighting because that blinks every 5-10secs that 10-30ms full power pulse.

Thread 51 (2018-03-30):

Can't connect to MQTT Server?

TerryLansdown, 2018-03-30:
Hi, thanks for your efforts on the sensor, very cool.

I get all the way through to flashing the board and looking at the serial port. It connects to my WIFI, but then won't connect to my MQTT server. I think the error is a 'can't establish a TCP connection'. I can ping the nodeMCU and it's live on my network and other devices are interacting with the Mosquitto server normally.

Any ideas?

I'm not using any internal security on the MQTT server, and it's set to allow anonymous connections.

The serial port reports:
```
calibrating sensor Starting Node named sensornode01

Connecting to ********
.......................................................................................................
WiFi connected
IP address:
192.168.0.106
Ready
IPess: 192.168.0.106
Attempting MQTT connection...failed, rc=-2 try again in 5 seconds
Attempting MQTT connection...failed, rc=-2 try again in 5 seconds
Attempting MQTT connection...failed, rc=-2 try again in 5 seconds
```

TerryLansdown, 2018-03-30:
Fixed it, I'd dumbly put 'http://' before my MQTT Server's IP.

Gah!

MischaI, 2018-09-21:
http:// doesnt help. I have steel "Attempting MQTT connection...failed, rc=-2 try again in 5 seconds"

Closed 2018-03-30.

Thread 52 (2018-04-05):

wdt timeout

jhavens12, 2018-04-05:
Is anyone else seeing the WDT timeout issues? For me, the sensor will work for a few days without issue and then it will drop offline. If you look at the console, it will show "wdt timeout ()" and freeze up until its physically unplugged and replugged in. Getting this with a few  ESP8266 boards. Anyone have any ideas?

mattlward, 2018-04-06:
I do not.. I have 3 sensing Wemos D1 mini's running espeasy and passing 2 values back to mqtt on a very regular basis.  A couple of them also have switches and they always respond.  I am running the Mosquito broker on Hassio.

mr-sneezy, 2018-04-26:
Do you have to have console running before the WDT, or is it readable after ?
Might check mine for this...

jhavens12, 2018-05-24:
Yes I've seen the WDT timeout when connected to the console, there is nothing after the wdt timeout line, just blank until the board is unplugged/replugged

SealedJoy, 2018-06-21:
Same problem here with wemos d1 mini

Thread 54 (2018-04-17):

Integration with Homeassistant

manojjenago, 2018-04-17:
Hi Ben,
I have configured as per the video. I can see the responses in Serial Monitor of Arduino.  I have made changes to configuration file( I am using Hassio). I have installed the mosquito mqtt broker.
{
  "plain": true,
  "ssl": false,
  "anonymous": true,
  "logins": [
    {
      "username": "homeassistant",
      "password": "xyz1234"
    }
  ],
  "customize": {
    "active": false,
    "folder": "mosquitto"
  },
  "certfile": "fullchain.pem",
  "keyfile": "privkey.pem"
}
My led turns on for the first time and after 2-3 seconds the switch again toggles automatically and all other sensors are shown as "Unknown". (but in Serial Monitor I can see the responses).
Also when I start the mosquito in hassio as add-in .

starting version 3.2.2
1523878259: mosquitto version 1.4.12 (build date 2017-06-01 13:03:48+0000) starting
1523878259: Config loaded from /etc/mosquitto.conf.
1523878259: Opening ipv4 listen socket on port 1883.
1523878259: Opening ipv6 listen socket on port 1883.
1523878259: Warning: Mosquitto should not be run as root/administrator.
1523878267: New connection from 172.30.32.1 on port 1883.
1523878268: Socket error on client <unknown>, disconnecting.
1523878268: New connection from 172.30.32.1 on port 1883.
1523878268: New client connected from 172.30.32.1 as fdea50aa-3554-4925-b218-dd7056436b62 (c1, k60, u'homeassistant').
Please suggest ... I hope I am missing something here. I have also done a port forwarding  1883 port of my pi ip.

Also I see we only use here only 1 topic for light , motion and RBG is that correct??
Thanks ,
MJ

manojjenago, 2018-04-20:
Just an update , I got it working by setting up the MAX packet size = 512. Also I was using the andrino.exe so the sketchbooks are located in a different location.

Thanks Ben for a wonderful video.  Also a request can you please add to read the data from a soil Moisture Water Sensor (https://www.amazon.com/gp/product/B01FDGUHBM/ref=oh_aui_detailpage_o00_s00?ie=UTF8&psc=1) Planning to add for automate the watering plants based on moisture..

Closed 2018-04-20.

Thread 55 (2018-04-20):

Soil moisture sensor

manojjenago, 2018-04-20:
A request can you please add to read the data from a soil Moisture Water Sensor (https://www.amazon.com/gp/product/B01FDGUHBM/ref=oh_aui_detailpage_o00_s00?ie=UTF8&psc=1) Planning to add for automate the watering plants based on moisture..

MJ

manojjenago, 2018-04-26:
Please let me know , if we can add the soil moisture sensor to it??

mattlward, 2018-04-30:
I have these working on the digial I/O.  So a 1 or 0 depending upon water presence.  I have not tried them in an analog fashion yet.  But, I am not looking at soil moisture, but I am looking at basement moisture for a failed sump pump.

consolacion, 2018-07-14:
Ideally you would connect it to A0, but that's taken. The module you linked to has a digital output, but that only gives you a Boolean level indication. If that suffices, you can connect it to a free pin, otherwise you may need to ditch the LDR.
If you really need both, get a cheap PCF8591 ADC->I2C board

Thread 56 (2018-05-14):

Invalid config for [sensor.mqtt]: value is not allowed for dictionary value @ data[‘device_class’]. Got ‘motion’. (See ?, line ?). Please check the docs at https://home-assistant.io/components/sensor.mqtt/

cooljimy84, 2018-05-14:
Just upgraded to 0.69.1 (finally as Ubuntu 18.04 is now out and using new python)

but seem to be getting this error and my motion sensors are not showing up.

Invalid config for [sensor.mqtt]: value is not allowed for dictionary value @ data[‘device_class’]. Got ‘motion’. (See ?, line ?). Please check the docs at https://home-assistant.io/components/sensor.mqtt/

cooljimy84, 2018-05-14:
fixed, for some reason i had
device_class: motion
set in the yaml config.

Closed 2018-05-14.

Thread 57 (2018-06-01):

Bruh Multisensor unable to set PIR value and status in Openhab

msgowdara, 2018-06-01:
I am beginner. I am using Openhab2. I can eaxtract Temp, Humidity and LDR, but unable to extract PIR motion status to Openhab2 Basic UI.

My item is as below
String    LivingRoom_Motion           "Motion Sensor [JSONPATH($.motion):%.1f]"     <door>        (LivingRoom, gMotion)              { mqtt="<[mqttbroker:home/livingroom:state:JSONPATH($.motion)]" }

I am getting "Err" value beside motion in Basic UI.

What should be the item type (I tried Switch, Number and Contact but no success).

Kindly help me in item creation to fetch value.

I am getting following JSON value from sensor

home/livingroom {"state":"OFF","color":{"r":255,"g":255,"b":255},"brightness":255,"humidity":"59.60","motion":"standby","ldr":"9","temperature":"31.70","heatIndex":"27.37"}

Kindly help.

kberck, 2018-06-21:
String MotionSense "Motion [%s]" <motion>
	{ mqtt="<[mqttbroker:home/livingroom:state:JSONPATH($.motion)]" }

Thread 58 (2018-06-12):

Constant ESP reboots

boardyuk, 2018-06-12:
Hi,

I've just setup 1 of these nodes to test as I want to have motion detection for some of the rooms in my house to control the lights with Home Assistant, however I'm experiencing a constant reboot of the ESP which is a little strange. I've got the ESP connected to my PC via USB to watch the serial monitor for the time being to ensure all messages are getting to MQTT.

Every few minutes (no specific timeout) the ESP is rebooting itself. I've got all the sensors connected except the RGB LED as I'm still waiting for those to arrive and I'm also undecided if I want the LED on all the nodes. The error I'm getting is -

`rst cause:2, boot mode:(3,7)

load 0x4010f000, len 1384, room 16
tail 8
chksum 0x2d
csum 0x2d
v614f7c32
~ld`

I've had a look and it seems to be related to a reset pin, however I can't really see what's going on. Can anyone help me please?

Thanks!

mr-sneezy, 2018-06-12:
I had similar bugs.
One thing that helped I think was to follow this information below in the link and add the pin assignments that were missed in the original code. My RGB led now behaves as expected and I seem to have got rid of most if not all random resets at the same time...
https://github.com/bruhautomation/ESP-MQTT-JSON-Multisensor/issues/38
Also there is a branch that has the 'random -ve sensor value data after reset' fixed, but I could not find it right now...

simonfell, 2018-06-25:
FWIW i have now found that the 2 sensors that i have built and configured seem to interfere with each other causing them to constantly reboot.  If i disconnect 1 the other is great.  I am guessing there is a simple solution, but i am struggling to see it at the moment.
Any ideas???

Si

consolacion, 2018-07-14:
When you built the 2nd one, did you give it its own mqtt client name?

boardyuk, 2018-08-09:
I haven't yet found a solution to this. I've actually ripped out the RGB LED code from the sketch as I have no need for the LED and it still reboots.

I'm lost as to what is causing this really.

danielgonzacas, 2018-12-26:
you can try upload the sketch selecting Arduino/tools/erase flash/ sketch + wifi settings, maybe it can help you.

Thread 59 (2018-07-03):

Feature request - Sounder device

mr-sneezy, 2018-07-03:
Is it possible to add functionality for a buzzer drive from a spare I/O (like D8 perhaps) and control it by MQTT commands. For a door chime beeper from HA or general purpose audible alert from HA ?

consolacion, 2018-07-14:
Yes I guess it is, but as Ben hasn't been very active lately, I think you'd better put it in yourself, rather than weight for it to be included

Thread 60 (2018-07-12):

Feature request - BME280 Sensor Support

cmacnichol, 2018-07-12:
Wondering how hard it would be to add support for the Bosch BME280 Sensor.  Have a few on order, might give it a go myself once I get them.  Really just wanted to see if anyone else has already done it or not.

The sensor supports Temp, Hum, and Pressure.  All over and I2C connection.

https://www.adafruit.com/product/2652

Well, that and to see if there is any life left on this project.  Seems like a lot of people are using it with HA, but this has not been updated in some time.

consolacion, 2018-07-14:
it is in fact not so hard to do that. You need to connect it to the I2C pins. Standard these are D1 and D2. These are however taken up by the red and green pin. Though it is possible to use other I2C pins, it might be easiest to give the red and green pin other vales like D4 and D6.
Then it is just a matter of adding the library, chosing the right mode and doing a read that you add to the JSON

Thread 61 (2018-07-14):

Contast reboots

therains, 2018-07-14:
I have been using these sensors for the past year and have gone to flash another today and am seeing constant reboots, i tried this on two different chips any idea what the issue may be ?

load 0x4010f000, len 1384, room 16
tail 8
chksum 0x2d
csum 0x2d
v614f7c32
~ld
calibrating sensor Starting Node named sensornode1

Connecting to xxxxxxxxxxxxxxxxxxxxxxxx
.....
WiFi connected
IP address:
192.168.1.105
Ready
IPess: x
Attempting MQTT connection...connected
Setting LEDs:
r: 0, g: 0, b: 0
{"state":"OFF","color":{"r":255,"g":255,"b":255},"brightness":255,"humidity":"0.00","motion":"","ldr":"0","temperature":"0.00","heatIndex":"nan"}
{"state":"OFF","color":{"r":255,"g":255,"b":255},"brightness":255,"humidity":"0.00","motion":"standby","ldr":"0","temperature":"0.00","heatIndex":"nan"}
resettin⸮
 ets Jan  8 2013,rst cause:2, boot mode:(3,2)

load 0x4010f000, len 1384, room 16
tail 8
chksum 0x2d
csum 0x2d
v614f7c32
~ld
calibrating sensor Starting Node named sensornode1

therains, 2018-07-14:
Downgraded ide to the version the previous chips where flashed on. Same cable and port/cable . Resvoled my issue

Closed 2018-07-14.

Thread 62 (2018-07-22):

Adapting the code to a Common Anode RGB LED

swamaway, 2018-07-22:
How should I adapt the code to support a Common anode RGB LED ? I have the second pin connected to 5V and the RGB pins attached as before.

Thank you

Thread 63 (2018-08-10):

Error parsing value: 'dict object' has no attribute 'temperature'

mr-sneezy, 2018-08-10:
Hey guys,
Since reflashing the multisensors with DanielXYZ2000 code revision I've not had any more problems with rubbish 0 values in the HomeAssistant sensor charts. However I do still get these HA internal log errors each time a multisensor either restarts itself, or maybe after a long period with little sensor change (sometimes not for days, then sometimes twice a day, it's very random).
While the 'Error parsing' messages are not stopping anything working, they do distract me from see more crucial info in the logs.
I'd like to eliminate them.

Any of you know why HA still sees a problem with the DHT22 part of the MQTT  ?

This is what I get in the logs in a block randomly, alway for the DHT22 related values...
`018-08-10 17:18:17 ERROR (MainThread) [homeassistant.helpers.template] Error parsing value: 'dict object' has no attribute 'humidity' (value: {"state":"OFF","color":{"r":255,"g":255,"b":255},"brightness":255,"motion":"standby","ldr":"0"}, template: {{ value_json.humidity | round(1) }})
2018-08-10 17:18:17 ERROR (MainThread) [homeassistant.helpers.template] Error parsing value: 'dict object' has no attribute 'heatIndex' (value: {"state":"OFF","color":{"r":255,"g":255,"b":255},"brightness":255,"motion":"standby","ldr":"0"}, template: {{ value_json.heatIndex | round(1) }})
2018-08-10 17:18:17 ERROR (MainThread) [homeassistant.helpers.template] Error parsing value: 'dict object' has no attribute 'temperature' (value: {"state":"OFF","color":{"r":255,"g":255,"b":255},"brightness":255,"motion":"standby","ldr":"0"}, template: {{ value_json.temperature | round(1) }})
2018-08-10 17:18:17 ERROR (MainThread) [homeassistant.helpers.template] Error parsing value: 'dict object' has no attribute 'humidity' (value: {"state":"OFF","color":{"r":255,"g":255,"b":255},"brightness":255,"motion":"standby","ldr":"0"}, template: {{ value_json.humidity | round(1) }})
2018-08-10 17:18:17 ERROR (MainThread) [homeassistant.helpers.template] Error parsing value: 'dict object' has no attribute 'heatIndex' (value: {"state":"OFF","color":{"r":255,"g":255,"b":255},"brightness":255,"motion":"standby","ldr":"0"}, template: {{ value_json.heatIndex | round(1) }})
2018-08-10 17:18:17 ERROR (MainThread) [homeassistant.helpers.template] Error parsing value: 'dict object' has no attribute 'temperature' (value: {"state":"OFF","color":{"r":255,"g":255,"b":255},"brightness":255,"motion":"standby","ldr":"0"}, template: {{ value_json.temperature | round(1) }})
2018-08-10 17:18:17 ERROR (MainThread) [homeassistant.helpers.template] Error parsing value: 'dict object' has no attribute 'humidity' (value: {"state":"OFF","color":{"r":255,"g":255,"b":255},"brightness":255,"motion":"standby","ldr":"0"}, template: {{ value_json.humidity | round(1) }})
2018-08-10 17:18:17 ERROR (MainThread) [homeassistant.helpers.template] Error parsing value: 'dict object' has no attribute 'heatIndex' (value: {"state":"OFF","color":{"r":255,"g":255,"b":255},"brightness":255,"motion":"standby","ldr":"0"}, template: {{ value_json.heatIndex | round(1) }})
2018-08-10 17:18:17 ERROR (MainThread) [homeassistant.helpers.template] Error parsing value: 'dict object' has no attribute 'temperature' (value: {"state":"OFF","color":{"r":255,"g":255,"b":255},"brightness":255,"motion":"standby","ldr":"0"}, template: {{ value_json.temperature | round(1) }})
2018-08-10 17:22:40 ERROR (MainThread) [homeassistant.helpers.template] Error parsing value: 'dict object' has no attribute 'humidity' (value: {"state":"OFF","color":{"r":255,"g":255,"b":255},"brightness":255,"motion":"standby","ldr":"0"}, template: {{ value_json.humidity | round(1) }})
2018-08-10 17:22:40 ERROR (MainThread) [homeassistant.helpers.template] Error parsing value: 'dict object' has no attribute 'heatIndex' (value: {"state":"OFF","color":{"r":255,"g":255,"b":255},"brightness":255,"motion":"standby","ldr":"0"}, template: {{ value_json.heatIndex | round(1) }})
2018-08-10 17:22:40 ERROR (MainThread) [homeassistant.helpers.template] Error parsing value: 'dict object' has no attribute 'temperature' (value: {"state":"OFF","color":{"r":255,"g":255,"b":255},"brightness":255,"motion":"standby","ldr":"0"}, template: {{ value_json.temperature | round(1) }})
2018-08-10 17:22:40 ERROR (MainThread) [homeassistant.helpers.template] Error parsing value: 'dict object' has no attribute 'humidity' (value: {"state":"OFF","color":{"r":255,"g":255,"b":255},"brightness":255,"motion":"motion detected","ldr":"0"}, template: {{ value_json.humidity | round(1) }})
2018-08-10 17:22:40 ERROR (MainThread) [homeassistant.helpers.template] Error parsing value: 'dict object' has no attribute 'heatIndex' (value: {"state":"OFF","color":{"r":255,"g":255,"b":255},"brightness":255,"motion":"motion detected","ldr":"0"}, template: {{ value_json.heatIndex | round(1) }})
2018-08-10 17:22:40 ERROR (MainThread) [homeassistant.helpers.template] Error parsing value: 'dict object' has no attribute 'temperature' (value: {"state":"OFF","color":{"r":255,"g":255,"b":255},"brightness":255,"motion":"motion detected","ldr":"0"}, template: {{ value_json.temperature | round(1) }})
2018-08-10 17:22:40 ERROR (MainThread) [homeassistant.helpers.template] Error parsing value: 'dict object' has no attribute 'humidity' (value: {"state":"OFF","color":{"r":255,"g":255,"b":255},"brightness":255,"motion":"motion detected","ldr":"0"}, template: {{ value_json.humidity | round(1) }})
2018-08-10 17:22:40 ERROR (MainThread) [homeassistant.helpers.template] Error parsing value: 'dict object' has no attribute 'heatIndex' (value: {"state":"OFF","color":{"r":255,"g":255,"b":255},"brightness":255,"motion":"motion detected","ldr":"0"}, template: {{ value_json.heatIndex | round(1) }})
2018-08-10 17:22:40 ERROR (MainThread) [homeassistant.helpers.template] Error parsing value: 'dict object' has no attribute 'temperature' (value: {"state":"OFF","color":{"r":255,"g":255,"b":255},"brightness":255,"motion":"motion detected","ldr":"0"}, template: {{ value_json.temperature | round(1) }})`

mkomarac, 2018-10-19:
I have the same issue. have you manage to solve it?

mr-sneezy, 2018-10-20:
Nope. I have  V79.3 of HA and still get these errors. I think every time the SensorNode resets HA throws this list, and the SensorNode resets itself a couple of times a day on average.

tubalainen, 2018-11-18:
Yes, Ive got the same issue here as well.

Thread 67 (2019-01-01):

Not declared buffer size while compiling

mcsabi, 2019-01-01:
Any thoughts would be appreciated why I am receiving this error when compiling the code in Arduino:

Arduino: 1.8.5 (Windows 10), Board: "NodeMCU 1.0 (ESP-12E Module), 80 MHz, 4M (3M SPIFFS), v2 Prebuilt (MSS=536), Disabled, None, 115200"

C:\Users\xxxx\Documents\Arduino\Multisensor_Bruh\sketch_jan01a\sketch_jan01a.ino: In function 'bool processJson(char*)':

sketch_jan01a:260: error: 'StaticJsonBuffer' was not declared in this scope

   StaticJsonBuffer<BUFFER_SIZE> jsonBuffer;

   ^

sketch_jan01a:260: error: 'jsonBuffer' was not declared in this scope

   StaticJsonBuffer<BUFFER_SIZE> jsonBuffer;

                                 ^

sketch_jan01a:264: error: 'ArduinoJson::JsonObject' has no member named 'success'

   if (!root.success()) {

             ^

C:\Users\xxxx\Documents\Arduino\Multisensor_Bruh\sketch_jan01a\sketch_jan01a.ino: In function 'void sendState()':

sketch_jan01a:335: error: 'StaticJsonBuffer' was not declared in this scope

   StaticJsonBuffer<BUFFER_SIZE> jsonBuffer;

   ^

sketch_jan01a:335: error: 'jsonBuffer' was not declared in this scope

   StaticJsonBuffer<BUFFER_SIZE> jsonBuffer;

                                 ^

sketch_jan01a:340: error: invalid initialization of non-const reference of type 'ArduinoJson::JsonObject& {aka ArduinoJson670_0_0::ObjectRef&}' from an rvalue of type 'ArduinoJson670_0_0::ObjectRef'

   JsonObject& color = root.createNestedObject("color");

                                                      ^

sketch_jan01a:354: error: 'ArduinoJson::JsonObject' has no member named 'measureLength'

   char buffer[root.measureLength() + 1];

                    ^

sketch_jan01a:355: error: 'ArduinoJson::JsonObject' has no member named 'printTo'

   root.printTo(buffer, sizeof(buffer));

        ^

sketch_jan01a:355: error: 'buffer' was not declared in this scope

   root.printTo(buffer, sizeof(buffer));

                ^

exit status 1
'StaticJsonBuffer' was not declared in this scope

This report would have more information with
"Show verbose output during compilation"
option enabled in File -> Preferences.

per1234, 2019-01-02:
This error means you're using a version of ArduinoJson library that is not compatible with this code. The ArduinoJson library 6.x.x versions have breaking changes that make them not not work with code written for the ArduinoJson 5.x.x versions.

The recommended solution is to roll back to the newest 5.x.x release of ArduinoJson:
1. Sketch > Include Library > Manage Libraries...
1. Wait for the download to finish.
1. In the "Filter your search..." box, type "arduinojson".
1. In the search results, click on "ArduinoJson by Benoit Blanchon"
1. From the dropdown version menu, select "5.13.4".
1. Click "Install".
1. Wait for the installation to finish.
1. Click "Close'. The code should now compile.

The alternative solution is to update the code to work with the 6.x.x versions of ArduinoJson. You will find a guide to this here:
https://arduinojson.org/v6/doc/upgrade/

Reference:
https://arduinojson.org/v5/faq/error-jsonbuffer-was-not-declared-in-this-scope/

mcsabi, 2019-01-02:
Thanks a lot works like a charm with 5.13.4

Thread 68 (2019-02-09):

Sensor showing 0 values

slackdance, 2019-02-09:
Hello!

Ordered parts quite some time ago and made everything ready. Yesterday, the board came and i set it up. It's working and showing values, but looking at the history, i get quite a few 0 values. What can cause this? The card is showing information normally, and i dont see these values there (that i have noticed).

The lux sensor has not arrived yet, so this is not reporting - buying figured if this was causing the error, all values would be scrambled?

https://imgur.com/gallery/qCS4SMg

The negative temperature at the start was me forgetting to change to C.

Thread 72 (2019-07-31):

Temp reading at least 15 degrees low.

ebuford, 2019-07-31:
I have built the Multisensor with a DHT22 and NodeMCU along with the TEMT6000 & AM312 PIR.
I'm using the same Pinouts as the Multisensor Video shows.
I've flashed this a couple of times using the exact code straight out of this site and Each time it comes up reading at least 15 degrees F low. Also the humidity is low as well.
This lead me to believe that perhaps the DHT22 was bad. So I set out to test it.
I then set up the DHT22 and flashed it with this code https://simple-circuit.com/esp-12e-nodemcu-ssd1306-dht22-am2302/
And the temp and humidity was correct.
So I have returned to the original code,  trying to figure out what might be causing this to run so low.
I've read thorough the issues but it seems like all the issues with temp have been caused by heat build up in a case - so far these have not been in a case and are just laying out on my bench.
The only lines I have changed in the code are SSID & Password along with the MQTT info.
Any help would be appreciated.

RedDevilAustria, 2019-08-30:
Hi I have actually the same issue ... Does anyone have an idea?

ebuford, 2019-08-30:
@RedDevilAustria I researched this a lot and didn't get an answer.
I've played with the DHT22 a fair amount have deployed several around my place; but I just couldn't get them to work the Multisensor from BRUH Automation.
Recently Digiblur did a great video on building one very similar to the BRUH sensor so I made one without the LED (which I'm not using anyway) and it works great.
Here's the link to that one.
https://www.youtube.com/watch?v=9Yu57vjz7AY
Hopefully you're question will get more answers than mine did.

RedDevilAustria, 2019-08-30:
@ebuford : Thank you very much for the video - I'll give it a try - maybe the sensor works at some point - never give up coding ! :) Should I find something I'll share it

RedDevilAustria, 2019-09-01:
@ebuford: got it working now - inserted in the setup function after serial begin
-->dht.begin();

and in the loop function before reading the new temperature
--> delay(3500);
    float newTempValue = dht.readTemperature(IsFahrenheit);
    float newHumValue = dht.readHumidity();

this works fine for me now and reads super accurate. Hope this one works also for you!

ebuford, 2019-09-06:
@RedDevilAustria I have updated my code and will give it a try this weekend.
Thanks for sharing!

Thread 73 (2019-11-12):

Possible Battery Power

vtashev, 2019-11-12:
Have you consider powering the sensor in shitty location where there is no power

Any ideas for good battery options, eventually putting inside the box?

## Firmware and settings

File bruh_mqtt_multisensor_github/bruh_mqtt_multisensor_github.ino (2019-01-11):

/*
  .______   .______    __    __   __    __          ___      __    __  .___________.  ______   .___  ___.      ___   .___________. __    ______   .__   __.
  |   _  \  |   _  \  |  |  |  | |  |  |  |        /   \    |  |  |  | |           | /  __  \  |   \/   |     /   \  |           ||  |  /  __  \  |  \ |  |
  |  |_)  | |  |_)  | |  |  |  | |  |__|  |       /  ^  \   |  |  |  | `---|  |----`|  |  |  | |  \  /  |    /  ^  \ `---|  |----`|  | |  |  |  | |   \|  |
  |   _  <  |      /  |  |  |  | |   __   |      /  /_\  \  |  |  |  |     |  |     |  |  |  | |  |\/|  |   /  /_\  \    |  |     |  | |  |  |  | |  . `  |
  |  |_)  | |  |\  \-.|  `--'  | |  |  |  |     /  _____  \ |  `--'  |     |  |     |  `--'  | |  |  |  |  /  _____  \   |  |     |  | |  `--'  | |  |\   |
  |______/  | _| `.__| \______/  |__|  |__|    /__/     \__\ \______/      |__|      \______/  |__|  |__| /__/     \__\  |__|     |__|  \______/  |__| \__|

  Thanks much to @corbanmailloux for providing a great framework for implementing flash/fade with HomeAssistant https://github.com/corbanmailloux/esp-mqtt-rgb-led

  To use this code you will need the following dependancies: 
  
  - Support for the ESP8266 boards. 
        - You can add it to the board manager by going to File -> Preference and pasting http://arduino.esp8266.com/stable/package_esp8266com_index.json into the Additional Board Managers URL field.
        - Next, download the ESP8266 dependancies by going to Tools -> Board -> Board Manager and searching for ESP8266 and installing it.
  
  - You will also need to download the follow libraries by going to Sketch -> Include Libraries -> Manage Libraries
      - DHT sensor library 
      - Adafruit unified sensor
      - PubSubClient
      - ArduinoJSON
	  
  UPDATE 16 MAY 2017 by Knutella - Fixed MQTT disconnects when wifi drops by moving around Reconnect and adding a software reset of MCU
	           
  UPDATE 23 MAY 2017 - The MQTT_MAX_PACKET_SIZE parameter may not be setting appropriately due to a bug in the PubSub library. If the MQTT messages are not being transmitted as expected you may need to change the MQTT_MAX_PACKET_SIZE parameter in "PubSubClient.h" directly.
  
  UPDATE 27 NOV 2017 - Changed HeatIndex to built in function of DHT library. Added definition for fahrenheit or celsius

*/



#include <ESP8266WiFi.h>
#include <DHT.h>
#include <PubSubClient.h>
#include <ESP8266mDNS.h>
#include <WiFiUdp.h>
#include <ArduinoOTA.h>
#include <ArduinoJson.h>


/************ TEMP SETTINGS (CHANGE THIS FOR YOUR SETUP) *******************************/
#define IsFahrenheit true //to use celsius change to false

/************ WIFI and MQTT INFORMATION (CHANGE THESE FOR YOUR SETUP) ******************/
#define wifi_ssid "YourSSID" //type your WIFI information inside the quotes
#define wifi_password "YourWIFIpassword"
#define mqtt_server "your.mqtt.server.ip"
#define mqtt_user "yourMQTTusername" 
#define mqtt_password "yourMQTTpassword"
#define mqtt_port 1883



/************* MQTT TOPICS (change these topics as you wish)  **************************/
#define light_state_topic "bruh/sensornode1"
#define light_set_topic "bruh/sensornode1/set"

const char* on_cmd = "ON";
const char* off_cmd = "OFF";



/**************************** FOR OTA **************************************************/
#define SENSORNAME "sensornode1"
#define OTApassword "YouPassword" // change this to whatever password you want to use when you upload OTA
int OTAport = 8266;



/**************************** PIN DEFINITIONS ********************************************/
const int redPin = D1;
const int greenPin = D2;
const int bluePin = D3;
#define PIRPIN    D5
#define DHTPIN    D7
#define DHTTYPE   DHT22
#define LDRPIN    A0



/**************************** SENSOR DEFINITIONS *******************************************/
float ldrValue;
int LDR;
float calcLDR;
float diffLDR = 25;

float diffTEMP = 0.2;
float tempValue;

float diffHUM = 1;
float humValue;

int pirValue;
int pirStatus;
String motionStatus;

char message_buff[100];

int calibrationTime = 0;

const int BUFFER_SIZE = 300;

#define MQTT_MAX_PACKET_SIZE 512


/******************************** GLOBALS for fade/flash *******************************/
byte red = 255;
byte green = 255;
byte blue = 255;
byte brightness = 255;

byte realRed = 0;
byte realGreen = 0;
byte realBlue = 0;

bool stateOn = false;

bool startFade = false;
unsigned long lastLoop = 0;
int transitionTime = 0;
bool inFade = false;
int loopCount = 0;
int stepR, stepG, stepB;
int redVal, grnVal, bluVal;

bool flash = false;
bool startFlash = false;
int flashLength = 0;
unsigned long flashStartTime = 0;
byte flashRed = red;
byte flashGreen = green;
byte flashBlue = blue;
byte flashBrightness = brightness;



WiFiClient espClient;
PubSubClient client(espClient);
DHT dht(DHTPIN, DHTTYPE);



/********************************** START SETUP*****************************************/
void setup() {

  Serial.begin(115200);

  pinMode(PIRPIN, INPUT);
  pinMode(DHTPIN, INPUT);
  pinMode(LDRPIN, INPUT);

  Serial.begin(115200);
  delay(10);

  ArduinoOTA.setPort(OTAport);

  ArduinoOTA.setHostname(SENSORNAME);

  ArduinoOTA.setPassword((const char *)OTApassword);

  Serial.print("calibrating sensor ");
  for (int i = 0; i < calibrationTime; i++) {
    Serial.print(".");
    delay(1000);
  }

  Serial.println("Starting Node named " + String(SENSORNAME));


  setup_wifi();

  client.setServer(mqtt_server, mqtt_port);
  client.setCallback(callback);


  ArduinoOTA.onStart([]() {
    Serial.println("Starting");
  });
  ArduinoOTA.onEnd([]() {
    Serial.println("\nEnd");
  });
  ArduinoOTA.onProgress([](unsigned int progress, unsigned int total) {
    Serial.printf("Progress: %u%%\r", (progress / (total / 100)));
  });
  ArduinoOTA.onError([](ota_error_t error) {
    Serial.printf("Error[%u]: ", error);
    if (error == OTA_AUTH_ERROR) Serial.println("Auth Failed");
    else if (error == OTA_BEGIN_ERROR) Serial.println("Begin Failed");
    else if (error == OTA_CONNECT_ERROR) Serial.println("Connect Failed");
    else if (error == OTA_RECEIVE_ERROR) Serial.println("Receive Failed");
    else if (error == OTA_END_ERROR) Serial.println("End Failed");
  });
  ArduinoOTA.begin();
  Serial.println("Ready");
  Serial.print("IPess: ");
  Serial.println(WiFi.localIP());
  reconnect();
}




/********************************** START SETUP WIFI*****************************************/
void setup_wifi() {

  delay(10);
  Serial.println();
  Serial.print("Connecting to ");
  Serial.println(wifi_ssid);

  WiFi.mode(WIFI_STA);
  WiFi.begin(wifi_ssid, wifi_password);

  while (WiFi.status() != WL_CONNECTED) {
    delay(500);
    Serial.print(".");
  }

  Serial.println("");
  Serial.println("WiFi connected");
  Serial.println("IP address: ");
  Serial.println(WiFi.localIP());
}



/********************************** START CALLBACK*****************************************/
void callback(char* topic, byte* payload, unsigned int length) {
  Serial.print("Message arrived [");
  Serial.print(topic);
  Serial.print("] ");

  char message[length + 1];
  for (int i = 0; i < length; i++) {
    message[i] = (char)payload[i];
  }
  message[length] = '\0';
  Serial.println(message);

  if (!processJson(message)) {
    return;
  }

  if (stateOn) {
    // Update lights
    realRed = map(red, 0, 255, 0, brightness);
    realGreen = map(green, 0, 255, 0, brightness);
    realBlue = map(blue, 0, 255, 0, brightness);
  }
  else {
    realRed = 0;
    realGreen = 0;
    realBlue = 0;
  }

  startFade = true;
  inFade = false; // Kill the current fade

  sendState();
}



/********************************** START PROCESS JSON*****************************************/
bool processJson(char* message) {
  StaticJsonBuffer<BUFFER_SIZE> jsonBuffer;

  JsonObject& root = jsonBuffer.parseObject(message);

  if (!root.success()) {
    Serial.println("parseObject() failed");
    return false;
  }

  if (root.containsKey("state")) {
    if (strcmp(root["state"], on_cmd) == 0) {
      stateOn = true;
    }
    else if (strcmp(root["state"], off_cmd) == 0) {
      stateOn = false;
    }
  }

  // If "flash" is included, treat RGB and brightness differently
  if (root.containsKey("flash")) {
    flashLength = (int)root["flash"] * 1000;

    if (root.containsKey("brightness")) {
      flashBrightness = root["brightness"];
    }
    else {
      flashBrightness = brightness;
    }

    if (root.containsKey("color")) {
      flashRed = root["color"]["r"];
      flashGreen = root["color"]["g"];
      flashBlue = root["color"]["b"];
    }
    else {
      flashRed = red;
      flashGreen = green;
      flashBlue = blue;
    }

    flashRed = map(flashRed, 0, 255, 0, flashBrightness);
    flashGreen = map(flashGreen, 0, 255, 0, flashBrightness);
    flashBlue = map(flashBlue, 0, 255, 0, flashBrightness);

    flash = true;
    startFlash = true;
  }
  else { // Not flashing
    flash = false;

    if (root.containsKey("color")) {
      red = root["color"]["r"];
      green = root["color"]["g"];
      blue = root["color"]["b"];
    }

    if (root.containsKey("brightness")) {
      brightness = root["brightness"];
    }

    if (root.containsKey("transition")) {
      transitionTime = root["transition"];
    }
    else {
      transitionTime = 0;
    }
  }

  return true;
}



/********************************** START SEND STATE*****************************************/
void sendState() {
  StaticJsonBuffer<BUFFER_SIZE> jsonBuffer;

  JsonObject& root = jsonBuffer.createObject();

  root["state"] = (stateOn) ? on_cmd : off_cmd;
  JsonObject& color = root.createNestedObject("color");
  color["r"] = red;
  color["g"] = green;
  color["b"] = blue;


  root["brightness"] = brightness;
  root["humidity"] = (String)humValue;
  root["motion"] = (String)motionStatus;
  root["ldr"] = (String)LDR;
  root["temperature"] = (String)tempValue;
  root["heatIndex"] = (String)dht.computeHeatIndex(tempValue, humValue, IsFahrenheit);


  char buffer[root.measureLength() + 1];
  root.printTo(buffer, sizeof(buffer));

  Serial.println(buffer);
  client.publish(light_state_topic, buffer, true);
}



/********************************** START SET COLOR *****************************************/
void setColor(int inR, int inG, int inB) {
  analogWrite(redPin, inR);
  analogWrite(greenPin, inG);
  analogWrite(bluePin, inB);

  Serial.println("Setting LEDs:");
  Serial.print("r: ");
  Serial.print(inR);
  Serial.print(", g: ");
  Serial.print(inG);
  Serial.print(", b: ");
  Serial.println(inB);
}



/********************************** START RECONNECT*****************************************/
void reconnect() {
  // Loop until we're reconnected
  while (!client.connected()) {
    Serial.print("Attempting MQTT connection...");
    // Attempt to connect
    if (client.connect(SENSORNAME, mqtt_user, mqtt_password)) {
      Serial.println("connected");
      client.subscribe(light_set_topic);
      setColor(0, 0, 0);
      sendState();
    } else {
      Serial.print("failed, rc=");
      Serial.print(client.state());
      Serial.println(" try again in 5 seconds");
      // Wait 5 seconds before retrying
      delay(5000);
    }
  }
}



/********************************** START CHECK SENSOR **********************************/
bool checkBoundSensor(float newValue, float prevValue, float maxDiff) {
  return newValue < prevValue - maxDiff || newValue > prevValue + maxDiff;
}


/********************************** START MAIN LOOP***************************************/
void loop() {

  ArduinoOTA.handle();
  
  if (!client.connected()) {
    // reconnect();
    software_Reset();
  }
  client.loop();

  if (!inFade) {

    float newTempValue = dht.readTemperature(IsFahrenheit);
    float newHumValue = dht.readHumidity();

    //PIR CODE
    pirValue = digitalRead(PIRPIN); //read state of the

    if (pirValue == LOW && pirStatus != 1) {
      motionStatus = "standby";
      sendState();
      pirStatus = 1;
    }

    else if (pirValue == HIGH && pirStatus != 2) {
      motionStatus = "motion detected";
      sendState();
      pirStatus = 2;
    }

    delay(100);

    if (checkBoundSensor(newTempValue, tempValue, diffTEMP)) {
      tempValue = newTempValue;
      sendState();
    }

    if (checkBoundSensor(newHumValue, humValue, diffHUM)) {
      humValue = newHumValue;
      sendState();
    }


    int newLDR = analogRead(LDRPIN);

    if (checkBoundSensor(newLDR, LDR, diffLDR)) {
      LDR = newLDR;
      sendState();
    }

  }

  if (flash) {
    if (startFlash) {
      startFlash = false;
      flashStartTime = millis();
    }

    if ((millis() - flashStartTime) <= flashLength) {
      if ((millis() - flashStartTime) % 1000 <= 500) {
        setColor(flashRed, flashGreen, flashBlue);
      }
      else {
        setColor(0, 0, 0);
        // If you'd prefer the flashing to happen "on top of"
        // the current color, uncomment the next line.
        // setColor(realRed, realGreen, realBlue);
      }
    }
    else {
      flash = false;
      setColor(realRed, realGreen, realBlue);
    }
  }

  if (startFade) {
    // If we don't want to fade, skip it.
    if (transitionTime == 0) {
      setColor(realRed, realGreen, realBlue);

      redVal = realRed;
      grnVal = realGreen;
      bluVal = realBlue;

      startFade = false;
    }
    else {
      loopCount = 0;
      stepR = calculateStep(redVal, realRed);
      stepG = calculateStep(grnVal, realGreen);
      stepB = calculateStep(bluVal, realBlue);

      inFade = true;
    }
  }

  if (inFade) {
    startFade = false;
    unsigned long now = millis();
    if (now - lastLoop > transitionTime) {
      if (loopCount <= 1020) {
        lastLoop = now;

        redVal = calculateVal(stepR, redVal, loopCount);
        grnVal = calculateVal(stepG, grnVal, loopCount);
        bluVal = calculateVal(stepB, bluVal, loopCount);

        setColor(redVal, grnVal, bluVal); // Write current values to LED pins

        Serial.print("Loop count: ");
        Serial.println(loopCount);
        loopCount++;
      }
      else {
        inFade = false;
      }
    }
  }
}




/**************************** START TRANSITION FADER *****************************************/
// From https://www.arduino.cc/en/Tutorial/ColorCrossfader
/* BELOW THIS LINE IS THE MATH -- YOU SHOULDN'T NEED TO CHANGE THIS FOR THE BASICS

  The program works like this:
  Imagine a crossfade that moves the red LED from 0-10,
    the green from 0-5, and the blue from 10 to 7, in
    ten steps.
    We'd want to count the 10 steps and increase or
    decrease color values in evenly stepped increments.
    Imagine a + indicates raising a value by 1, and a -
    equals lowering it. Our 10 step fade would look like:

    1 2 3 4 5 6 7 8 9 10
  R + + + + + + + + + +
  G   +   +   +   +   +
  B     -     -     -

  The red rises from 0 to 10 in ten steps, the green from
  0-5 in 5 steps, and the blue falls from 10 to 7 in three steps.

  In the real program, the color percentages are converted to
  0-255 values, and there are 1020 steps (255*4).

  To figure out how big a step there should be between one up- or
  down-tick of one of the LED values, we call calculateStep(),
  which calculates the absolute gap between the start and end values,
  and then divides that gap by 1020 to determine the size of the step
  between adjustments in the value.
*/
int calculateStep(int prevValue, int endValue) {
  int step = endValue - prevValue; // What's the overall gap?
  if (step) {                      // If its non-zero,
    step = 1020 / step;          //   divide by 1020
  }

  return step;
}

/* The next function is calculateVal. When the loop value, i,
   reaches the step size appropriate for one of the
   colors, it increases or decreases the value of that color by 1.
   (R, G, and B are each calculated separately.)
*/
int calculateVal(int step, int val, int i) {
  if ((step) && i % step == 0) { // If step is non-zero and its time to change a value,
    if (step > 0) {              //   increment the value if step is positive...
      val += 1;
    }
    else if (step < 0) {         //   ...or decrement it if step is negative
      val -= 1;
    }
  }

  // Defensive driving: make sure val stays in the range 0-255
  if (val > 255) {
    val = 255;
  }
  else if (val < 0) {
    val = 0;
  }

  return val;
}

/****reset***/
void software_Reset() // Restarts program from beginning but does not reset the peripherals and registers
{
Serial.print("resetting");
ESP.reset(); 
}

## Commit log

2017-04-11 add enclosure info
2017-04-11 corrected wiring diagram
2017-05-02 Dependancy spelling mistake
    Just in case someone is having a hard time finding the packages
    [bruh_mqtt_multisensor_github.ino]
2017-05-16 MQTT hangs on WIFI disconnect fix
    Added software reset.
    Redacted my connection info this time
    [bruh_mqtt_multisensor_github.ino]
2017-06-10 Enclosure V2
    I added a second version of my enclosure that moves the DHT22 sensor outside the case, removes the standoff for the LDR sensor, and adds a pocket for the LED. This should reduce most of the high temperatures being reported by the board and the removal of the standoff allows you to use either the TEMT600 sensor or photoresistor module. A dab of hot glue can help hold everything in place until you can snap the case together.
    [BRUH Multisensor V2.stl]
2017-06-10 Add 10 JUN 2017 Update
    New case, PIR shielding note
2017-11-27 Change to HeatIndex function using built in DHT library plus notes
    Now using dht.computerHeatIndex function, definition for fahrenheit or celsius, plus notes and typo fixes
    [bruh_mqtt_multisensor_github.ino]
